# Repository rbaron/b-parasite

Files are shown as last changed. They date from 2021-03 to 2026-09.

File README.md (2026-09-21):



# b-parasite
<p align="center">
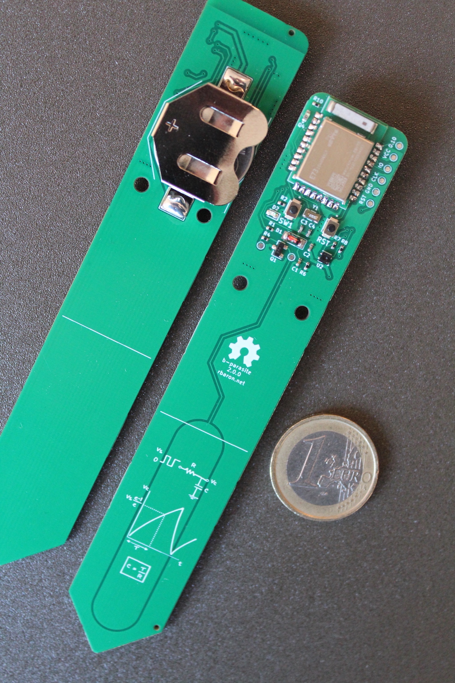
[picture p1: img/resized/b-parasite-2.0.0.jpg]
PCB front and back photo
  
</p>

b-parasite is an open source soil moisture and ambient temperature/humidity/light sensor.

# Features
* Capacitive Soil moisture sensor - see [this blog post](https://rbaron.net/blog/2021/04/05/How-capacitive-soil-moisture-sensors-work.html), [this Twitter thread](https://twitter.com/rbaron_/status/1367182806368071685), and [this post](https://wemakethings.net/2012/09/26/capacitance_measurement/) for nice resources on how they work
* Air temperature and humidity sensor using a [Sensirion's SHTC3](https://sensirion.com/media/documents/643F9C8E/63A5A436/Datasheet_SHTC3.pdf)
* Light sensor using an [ALS-PT19](https://en.everlight.com/wp-content/plugins/ItemRelationship/product_files/pdf/ALS-PT19-315C-L177-TR8_V8.pdf) phototransistor
* Powered by a common CR2032 coin cell, potentially for over two years
* Support for [nRF52840](https://www.nordicsemi.com/products/nrf52840) and [nRF52833](https://www.nordicsemi.com/products/nrf52833) modules
* Open hardware and open source design

# Software
This repository also hosts a few different firmware samples for b-parasite.

|Sample|Description|Extra Documentation|
|---|---|---|
|[samples/ble](./code/samples/ble)|This is the most battle-tested and useful firmware. It periodically reads all sensors and broadcast them via Bluetooth Low Energy (BLE). It works with [Home Assistant](https://www.home-assistant.io/) + [BTHome](https://bthome.io/) out of the box. |[Docs](./code/samples/ble/README.md)|
|[samples/zigbee](./code/samples/zigbee)| An experimental/educational/exploratory basic Zigbee sample built on [nRF Connect + ZBOSS](https://developer.nordicsemi.com/nRF_Connect_SDK/doc/latest/nrf/ug_zigbee.html). It integrates with [Home Assistant](https://www.home-assistant.io/) via [ZHA](https://www.home-assistant.io/integrations/zha) or [Zigbee2MQTT](https://www.zigbee2mqtt.io/). |[Docs](./code/samples/zigbee/README.md)|
|[samples/blinky](./code/samples/blinky)| The classic "Hello, world" |-|
|[samples/soil-read-loop](./code/samples/soil-read-loop)| Reads the soil moisture sensor on a loop. Useful for experimenting and calibrating the sensor. |-|
|[samples/input](./code/samples/input)| Handles button presses. Useful for power profiling GPIO interrupts and testing debouncing for push switches on [boards that have them](https://github.com/rbaron/b-parasite/wiki/Hardware-Versions). |-|

# Documentation
Information about how to order, assemble, build the samples, protect the sensor and flash the firmware is on [the Wiki](https://github.com/rbaron/b-parasite/wiki).

# Repository Organization
* [code/](./code/) - A [`west workspace`](https://docs.zephyrproject.org/latest/develop/west/workspaces.html) containing the common `prstlib` module library and samples, built with Nordic's [nRF Connect SDK](https://www.nordicsemi.com/Products/Development-software/nrf-connect-sdk).
* [kicad/](./kicad/) - KiCad schematic, layout and fabrication files for the printed circuit board (PCB)
* [data/](data/) - data for testing and sensor calibration
* [bridge/](bridge/) - an [ESPHome](https://github.com/esphome/esphome)-based BLE-MQTT bridge
* [case/](case/) - a 3D printable case

<p align="center">
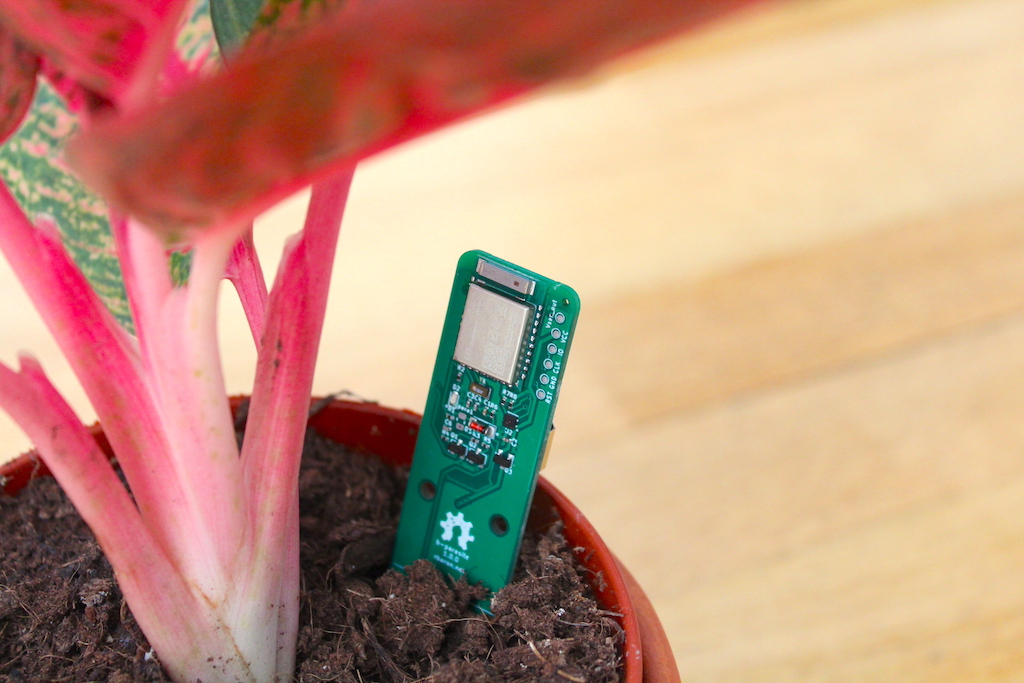
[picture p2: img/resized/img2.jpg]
b-parasite stuck into a small plant vase
  
</p>

# Case
<p align="center">
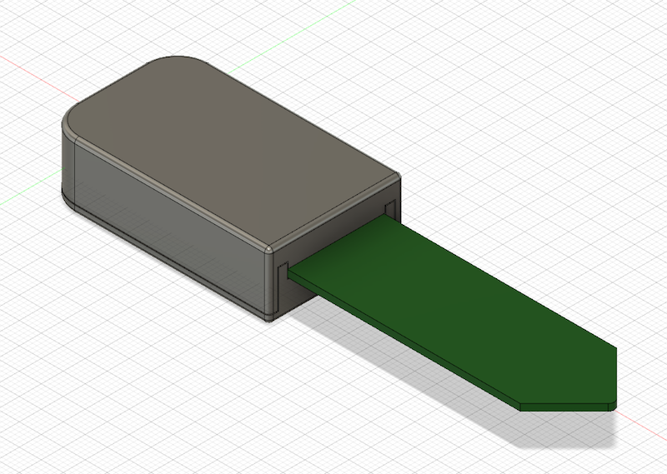
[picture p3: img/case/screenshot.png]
Render of the original 3D printable case
  
</p>

We have three different 3D-printable cases:
1. Original snap-on case - [case/Top.stl](./case/Top.stl), [case/Bottom.stl](./case/Bottom.stl)
2. High airflow - [case/b_parasite_case_high_airflow.stl](./case/b_parasite_case_high_airflow.stl)
3. Mushroom-style - available on [Printables](https://www.printables.com/model/456571-mushroomcap-for-b-parasite-soil-moisture-sensor)
4. b-parasite Hat - available on [Printables](https://www.printables.com/model/901220-waterproof-case-for-b-parasite-soil-moisture-air-s)

# Accessories

Designs and hardware to help you, when building your own:
1. Desk holder for b-parasites [Printables](https://www.printables.com/de/model/566974-b-parasite-holder)

# License
The hardware and associated design files are released under the [Creative Commons CC BY-SA 4.0 license](https://creativecommons.org/licenses/by-sa/4.0/).
The code is released under the [MIT license](https://opensource.org/licenses/MIT).

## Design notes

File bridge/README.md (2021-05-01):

# What's a Bridge (or a Hub)?
b-parasite periodically broadcasts its sensors readings via bluetooth low energy (BLE). Usually, a bridge (a separate device) is used for capturing those broadcasts, decoding them, and forwarding them somewhere else (like MQTT or directly to a database).

# An ESPHome-based Example Bridge
This directory contains a hub implementation based on the [ESPHome project](https://github.com/esphome/esphome/), which runs on the popular [ESP32](https://www.espressif.com/en/products/socs/esp32) microcontrollers.

The `parahub.yaml` file defines an ESPHome project using the `b_parasite` platform. This platform has not yet been merged in the official ESPHome repository, so if you want to use this example bridge, you'll need to use the [rbaron/esphome](https://github.com/rbaron/esphome) fork.

## Secrets
`parahub.yaml` contains some directives such as `!secret mqtt_password`, which instructs it to read secrets from a `secrets.yaml` file.

This file is usually not commited to version control, so you'll need to populate your own. Here's an example:

```yaml
# Example secrets.yaml
wifi_ssid: WIFI_NETWORK_NAME
wifi_password: WIFI_PASSWORD
mqtt_broker: MQTT_BROKER
mqtt_password: MQTT_PASSWORD
ota_password: OTA_PASSWORD
```

# Alternative
[parasite-scanner](https://github.com/rbaron/parasite-scanner) is a purpose-built BLE-MQTT bridge for b-parasites, and runs on Linux and macOS.

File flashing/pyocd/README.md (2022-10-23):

# Flashing with pyocd

This is a different approach to flash the firmware on the b-parasites. It is completely optional.

## Basic instructions

(Based on the discussion in issue #67)

The instructions will probably differ slightly depending on your debugging probe and hardware setup.

The setup is fairly straightforward and documented in the `pyocd` [docs](https://pyocd.io/).

I used an inexpensive debugging probe from Aliexpress called `nanoDAP` from `Muse Labs` which is less than 10 € and readily available. The J-LINKs are hard to get and quite expensive. In my understanding basically all `CMSIS-DAP`-compatible probes which are recognized by `pyocd` should work.

After connecting the debugging probe via usb and connecting the b-parasite as described in the wiki, flashing was easy and fast.

For a complete flashing of softdevice and firmware use the provided python script. Assuming you put the `*.hex` files in default locations it boils down to one simple command:

```
python ./flash_firmware.py
```

For help and documentation of the available command line flags use

```
python ./flash_firmware.py -h
```

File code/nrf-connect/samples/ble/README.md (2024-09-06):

# Bluetooth Low Energy (BLE)
In this sample, b-parasite sensors are periodically read and broadcast using Bluetooth Low Energy (BLE) dvertising packets.

## Configuration
Available configurations and their default values are in [`Kconfig`](./Kconfig). They are set in [`prj.conf`](./prj.conf). Here are some notable examples.

### Sleep Interval
To save energy, the board spends most of the time in a "deep sleep" state, in which most peripherals and radio are completely turned off. The period of sleep is controlled by the `PRST_SLEEP_DURATION_SEC` config.

### Advertising Duration
When it wakes up, the sample reads all sensors and keep broadcasting advertising packets for `PRST_BLE_ADV_DURATION_MSEC` before going back to sleep.

### Advertising Packet Encoding
There are different ways to encode the sensor data in a BLE advertising packet.

#### BTHome Encoding
[BTHome](https://bthome.io) is a new (as of Dec/2022) open standard for encoding sensor data in BLE applications. [Home Assistant](https://www.home-assistant.io/integrations/bthome/) supports it out of the box. This makes the deployment extra convenient, since no additional configuration is needed - Home Assistant will automatically detect b-parasites in range.

What's even more interesting is that by employing [ESPHome](https://esphome.io/) bridges with the [`bluetooth_proxy`](https://esphome.io/components/bluetooth_proxy.html) component, the range of BLE coverage can be transparently increased. Multiple ESPHome bridges will forward received BLE broadcasts to Home Assistant.

This is what a typical deployment with BTHome looks like:
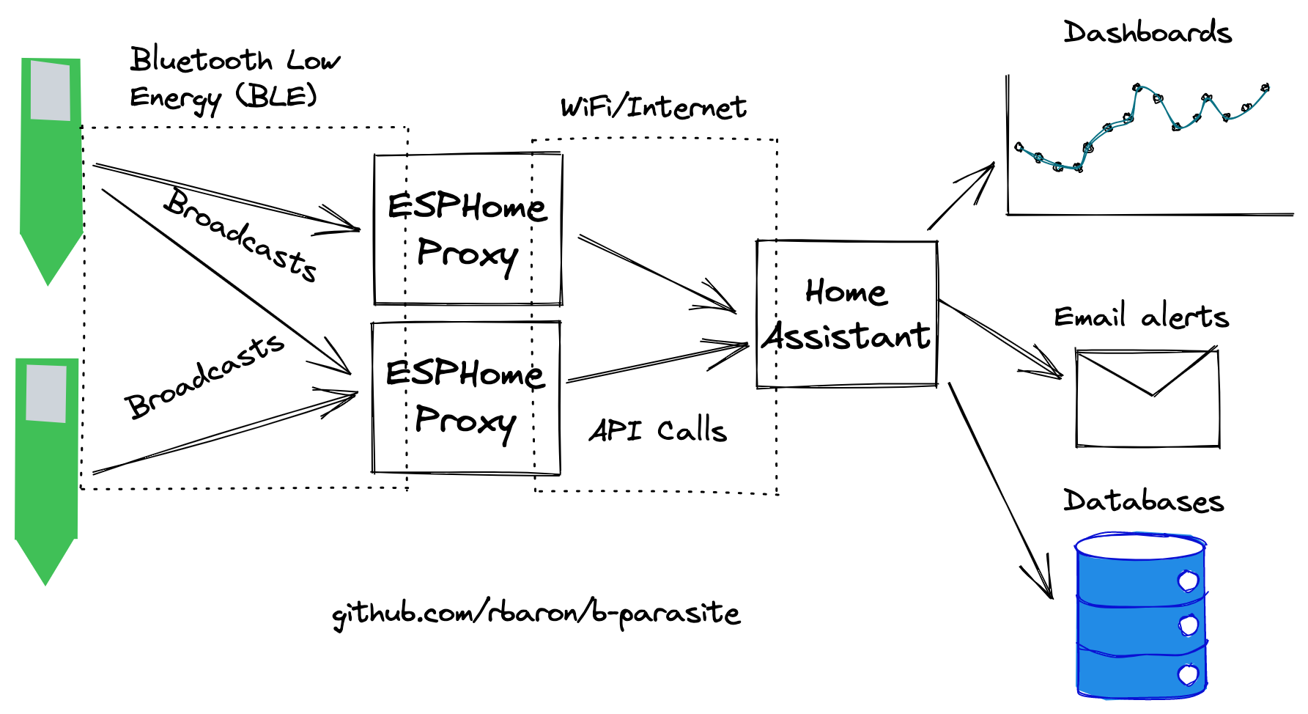
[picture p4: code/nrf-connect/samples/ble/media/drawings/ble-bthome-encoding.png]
Topology with BTHome + Home Assistant


There are two versions of BTHome encodings supported by this sample:
* `PRST_BLE_ENCODING_BTHOME_V2=y` (**default**) uses the [BTHome V2](https://bthome.io/format/), supported by Home Assistant since version `2022.12`
* `PRST_BLE_ENCODING_BTHOME_V1=y` uses the [legacy BTHome V1](https://bthome.io/v1/), which was briefly in use
#### b-parasite Encoding
`PRST_BLE_ENCODING_BPARASITE_V2=y` selects the legacy encoding, used historically in this project. This is the encoding that the [`b_parasite`](https://esphome.io/components/sensor/b_parasite.html) ESPHome component understands.

With this encoding and a ESPHome + `b_parasite` component, this is an usual deployment topology:

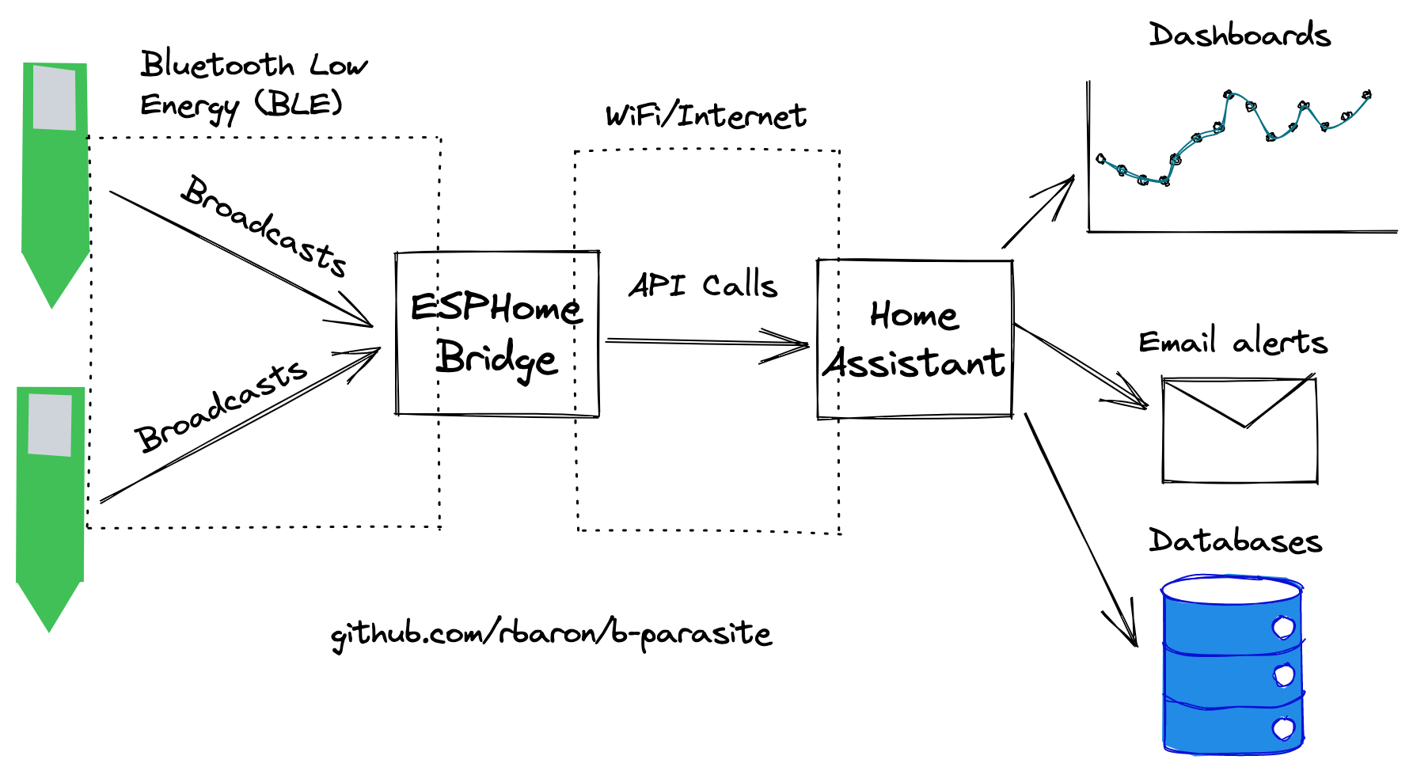
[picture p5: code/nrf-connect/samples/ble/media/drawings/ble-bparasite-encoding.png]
Topology with Legacy encoding + Home Assistant


The disadvantages of this encoding are:
- Each b-parasite has to be configured in the ESPHome component
- Range is limited, unless multiple ESPHome bridges are deployed with the same static configuration

## Battery Life
**tl;dr**: Theoretically well over two years with default settings.

While in deep sleep, the board consumes around `3.0 uA`:

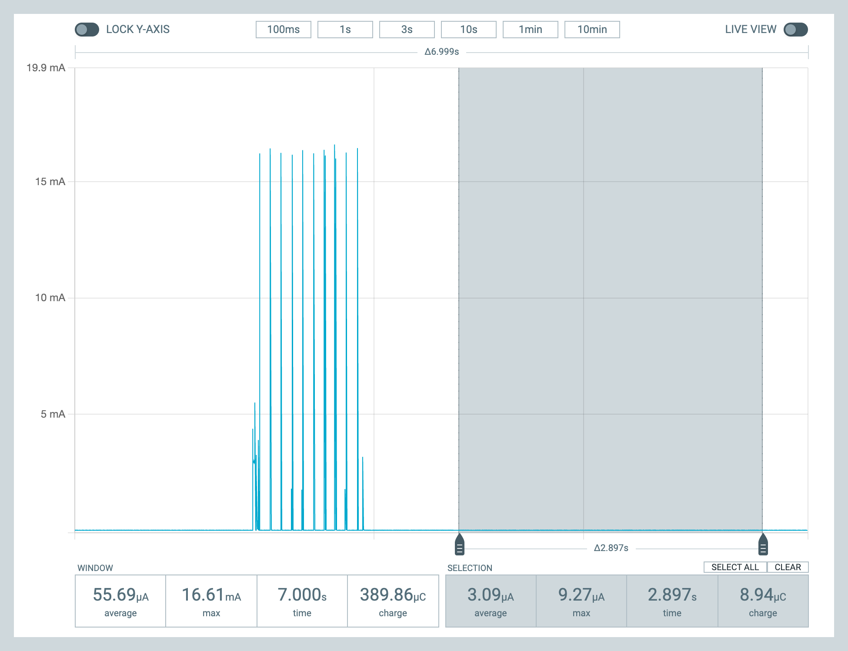
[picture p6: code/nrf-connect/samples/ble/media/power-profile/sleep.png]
Sleep current consumption


In the active broadcasting state, the average power consumption is highly dependant on the advertising interval.

With the default settings (in the `[30, 40] ms` range), we see an average of around `810 uA`:

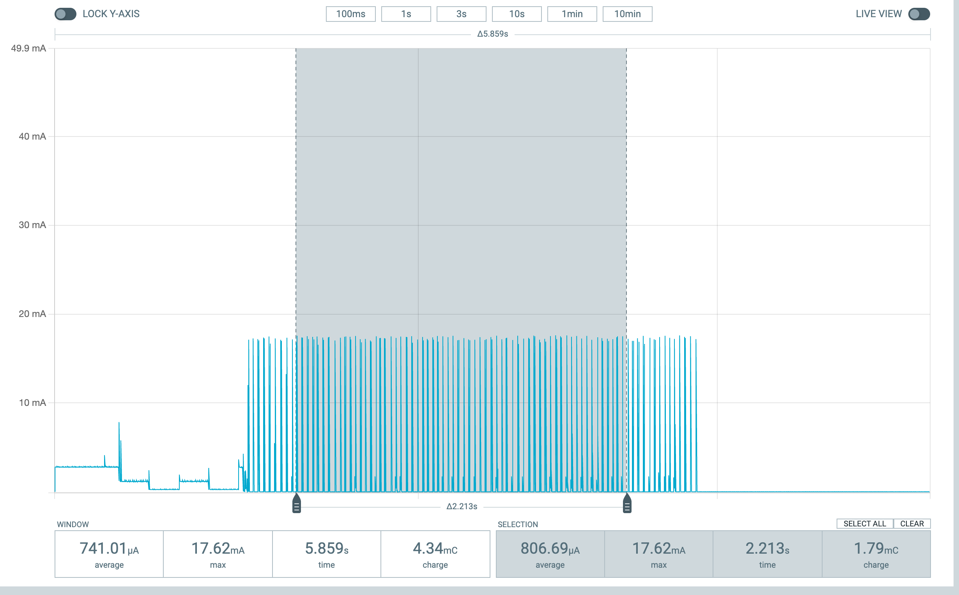
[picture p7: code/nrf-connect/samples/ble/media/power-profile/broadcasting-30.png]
Broadcasting with 30 ms current consumption


If for example we lower the connection interval to the SDK defaults (`[100, 150] ms`, roughly trading off range for power), the average current consumption is around `345 uA`:

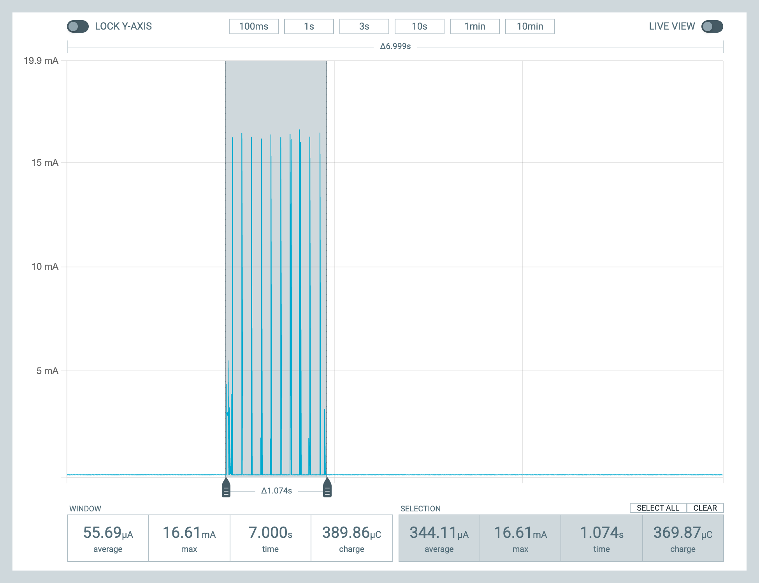
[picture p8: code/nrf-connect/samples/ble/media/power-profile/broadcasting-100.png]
Broadcasting with 100ms current consumption


With a `200 mAh` CR2032 battery, we can use [this spreadsheet](https://docs.google.com/spreadsheets/d/157JQiX20bGkTrlbvWbWRrs_WViL3MgVZffSCWRR7uAI/edit#gid=0) to estimate the battery life to over two years. Note that this is a simplified model and results in practice may vary.

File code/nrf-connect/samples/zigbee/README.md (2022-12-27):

# Zigbee firmware sample
This sample is adapted from the [zigbee_template](https://developer.nordicsemi.com/nRF_Connect_SDK/doc/latest/nrf/samples/zigbee/template/README.html) from the nRF Connect SDK. It's a basic experimental/educational/exploratory firmware sample for b-parasite.

## Clusters
These [clusters](https://en.wikipedia.org/wiki/Zigbee#Cluster_library) are defined in the sample:

|Cluster ID|Name|
|---|---|
|0x0001|Power Configuration|
|0x0400|Illuminance Measurement|
|0x0402|Temperature Measurement|
|0x0405|Relative Humidity Measurement|
|0x0408|Soil Moisture Measurement|

## Pairing Mode
The sample will first boot and start looking for a Zigbee coordinator - in pairing mode. The onboard LED will be flashing once a second while in this mode. Once a suitable network is found, the LED will briefly flash 3 times and remain off.

### Factory Reset
A factory reset will make b-parasite forget its network pairing information and switch to pairing mode. There are two (mutually exclusive) methods to perform a factory reset, controlled by the `CONFIG_PRST_ZB_FACTORY_RESET_METHOD` config flag.

#### Factory Reset Method 1 (default) - Double reset
Resetting b-parasite twice in the timestamp of 5 seconds will perform a factory reset. With this method, both shorting the `RST` pin to ground and removing-inserting the battery counts as a reset.

For better results, wait > 1 and < 5 seconds second between the resets. The LED will flash a total of 8 times to indicate it worked.

#### Factory Reset Method 2 - Reset Pin
In this method, there's a distinction between two reset modes.

#### Power up mode
The device enters this mode when it is powered. For example, swapping an old battery or connecting to eternal power. This is the "usual" reset mode, and joined networks will be remembered.

#### Reset pin mode
If the device's RESET pin is briefly grounded, the device will effectively be **factory reset**. The device will leave its previous network and start looking for a new one.

While it works, this method can be finicky - an accidental pin reset will perform an unwanted factory reset.

## Configs
Available options in `Kconfig`. Notable options:
* `CONFIG_PRST_ZB_SLEEP_DURATION_SEC`: amount of time (in seconds) the device sleeps between reading all sensors and updating its clusters
* `CONFIG_PRST_ZB_PARENT_POLL_INTERVAL_SEC`: amount of time (in seconds) the device waits between polling its parent for data

## Home Assistant Integration
This firmware sample has only been tested with Home Assistant, using one of the following integrations.

### Zigbee Home Automation (ZHA)
With the [ZHA](https://www.home-assistant.io/integrations/zha) Home Assistant integration, b-parasite should work out of the box.

### Zigbee2MQTT & Home Assistant
With [Zigbee2MQTT](https://zigbee2mqtt.io/), a custom converter is required. The [b-parasite.js](b-parasite.js) file contains such a converter. See [Support new devices](https://www.zigbee2mqtt.io/advanced/support-new-devices/01_support_new_devices.html) for instructions.

## Battery Life
While sleeping, the device consumes around 2 uA:
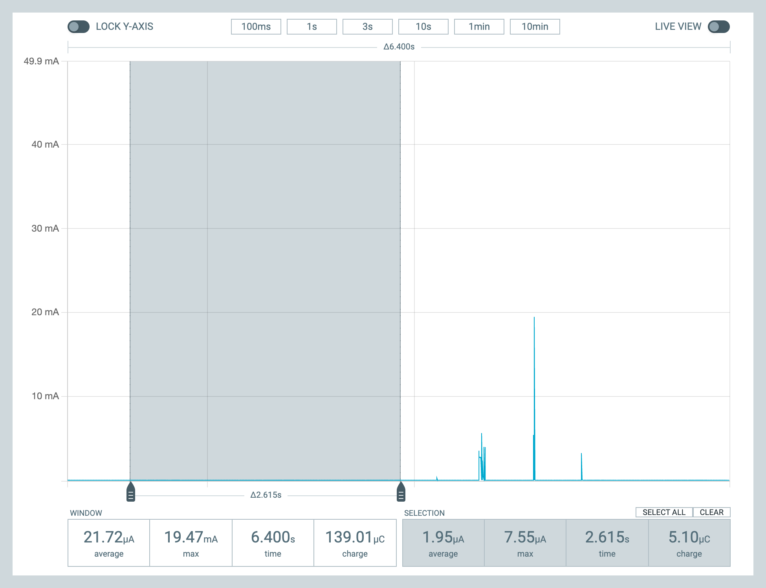
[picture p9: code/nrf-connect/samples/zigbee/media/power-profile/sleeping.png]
sleeping current

In the active cycle, it averages around 125 uA for 1 second:
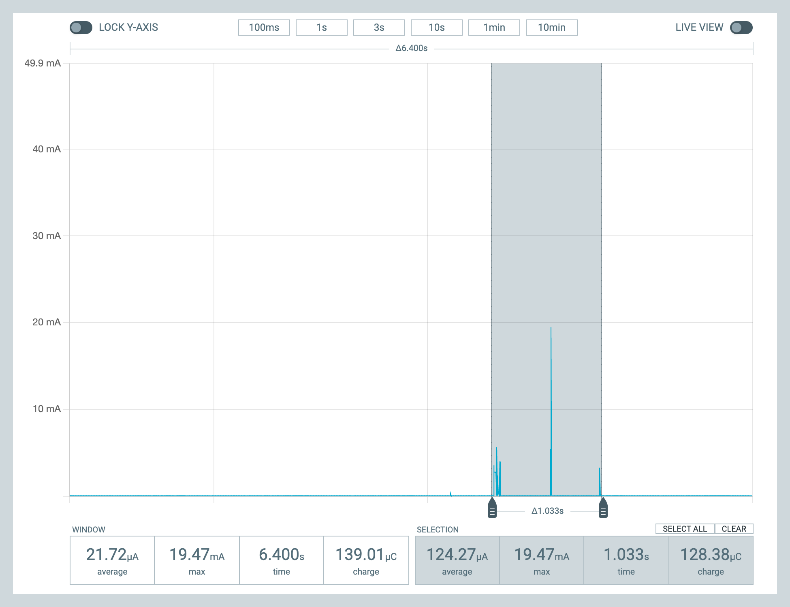
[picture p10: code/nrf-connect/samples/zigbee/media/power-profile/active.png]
active current


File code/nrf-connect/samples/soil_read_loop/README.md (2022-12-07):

# Calibration
A sample for calibrating b-parasites soil moisture analog-to-digital conversion.

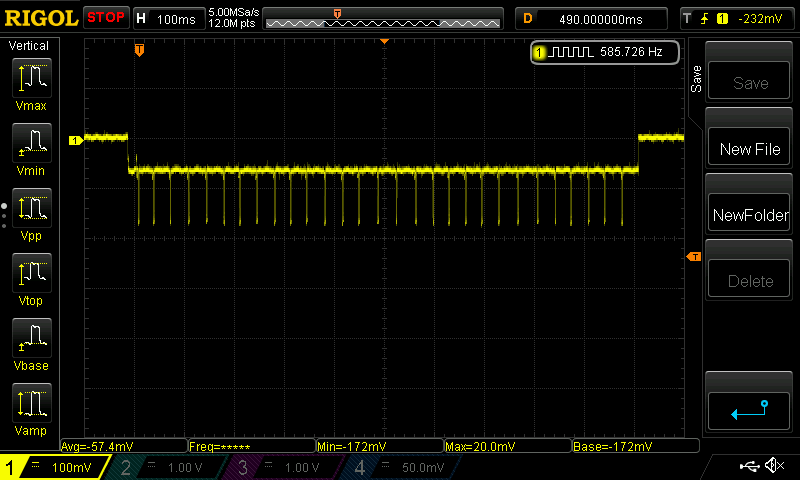
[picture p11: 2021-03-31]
img/scope/0dbm-no-led-across-10ohm.png

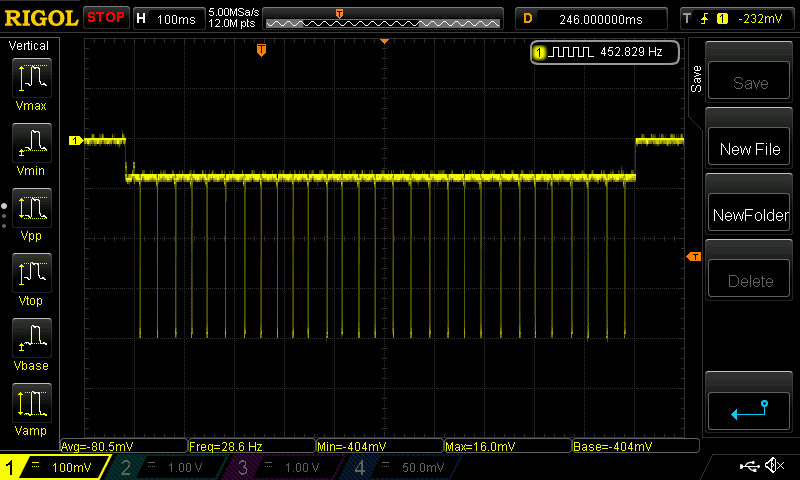
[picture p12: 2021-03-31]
img/scope/8dbm-across-10ohm.png

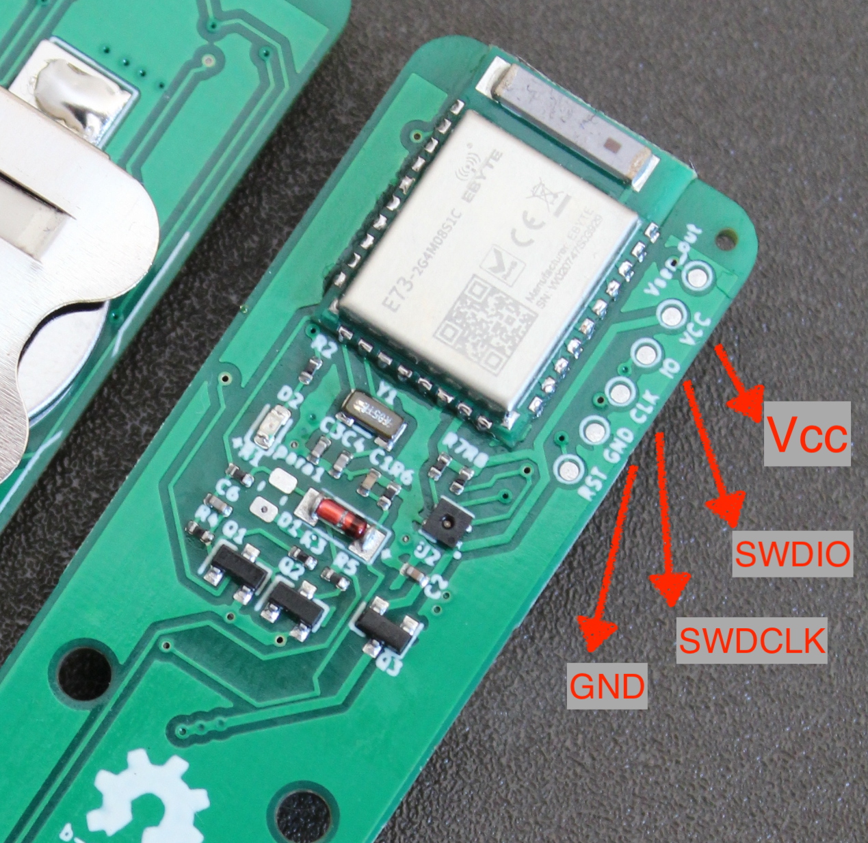
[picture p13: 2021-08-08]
img/wiki/swdpins.jpg

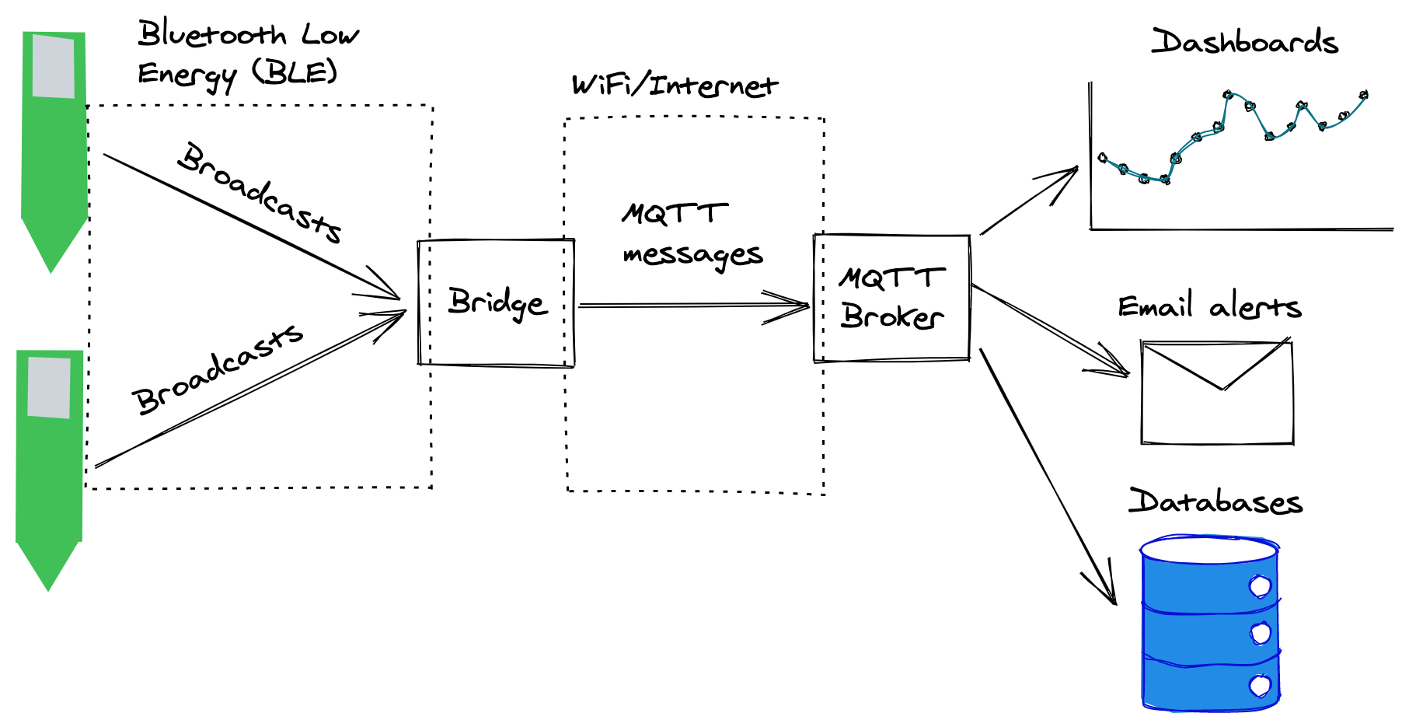
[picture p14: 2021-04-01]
img/excalidraw/diagram.png

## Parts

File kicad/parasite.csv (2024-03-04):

Comment | Designator | Footprint | LCSC
Battery_Cell | BT1 | kicad:BatteryHolder_Keystone_3002_1x2032
1n | C1 | Capacitor_SMD:C_0402_1005Metric | C1523
100n | C2 | Capacitor_SMD:C_0402_1005Metric | C1525
12p | C3,C4 | Capacitor_SMD:C_0402_1005Metric | C1547
LL4148 | D1 | Diode_SMD:D_MiniMELF | C3011166
LED | D2 | LED_SMD:LED_0603_1608Metric | C2286
MMBT3906 | Q1 | Package_TO_SOT_SMD:SOT-23 | C2910191
Q_Photo_NPN | Q4 | snapeda:TR8 | C146233
10k | R1,R4,R7,R8 | Resistor_SMD:R_0402_1005Metric | C25744
470 | R10 | Resistor_SMD:R_0402_1005Metric | C25117
1k | R2 | Resistor_SMD:R_0402_1005Metric | C11702
1M | R6 | Resistor_SMD:R_0402_1005Metric | C26083
B3U-1000P | RST1,SW1 | SW_B3U-1000P | C231329
E73-2G4M08S1C | U1 | snapeda:E73-2G4M08S1C | C356849
SHTC3 | U2 | kicad:Sensirion_DFN-4-1EP_2x2mm_P1mm_EP0.7x1.6mm | C194656
32.768kHz | Y1 | Crystal:Crystal_SMD_3215-2Pin_3.2x1.5mm | C32346

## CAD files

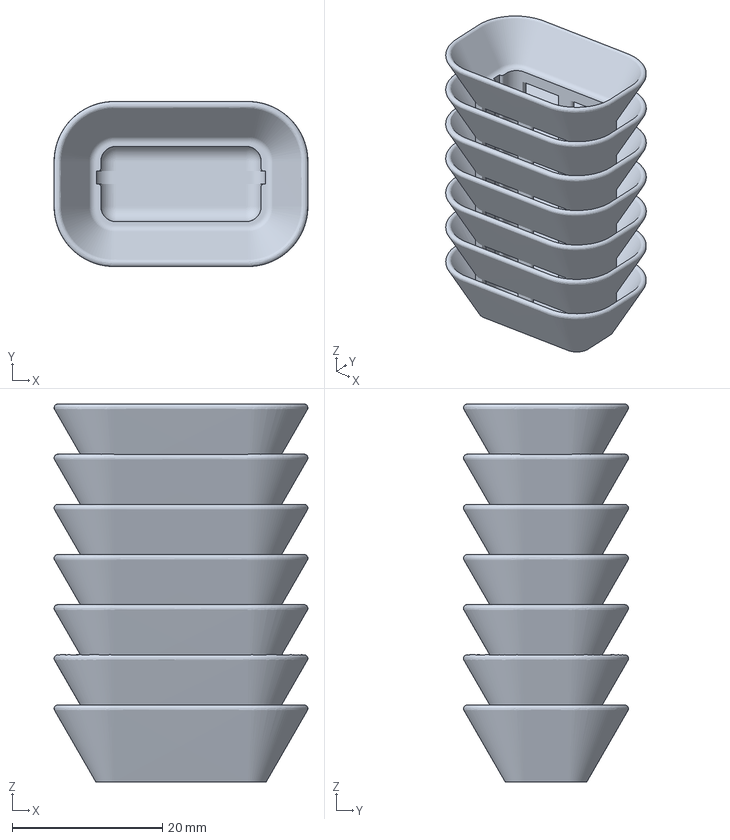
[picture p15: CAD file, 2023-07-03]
case/b_parasite_case_high_airflow.3mf
33.7 x 21.9 x 50.3 mm

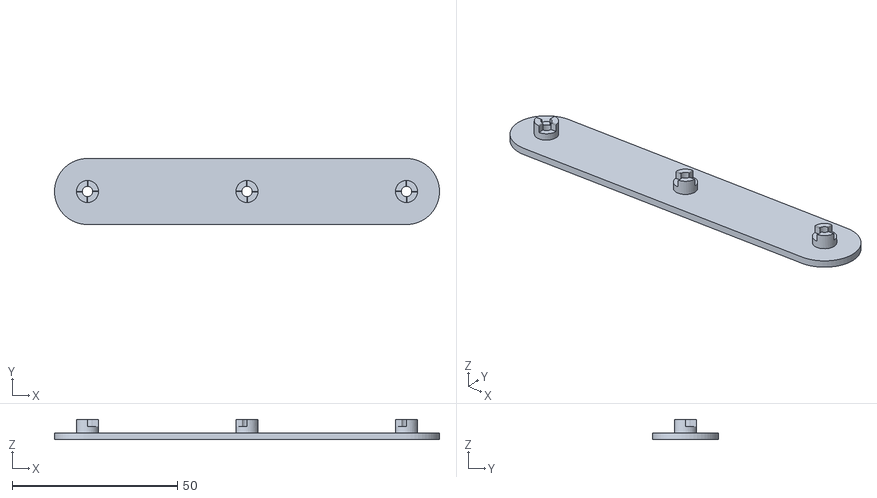
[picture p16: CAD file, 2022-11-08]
experimental/rotisserie/base.stl
116.6 x 20.0 x 6.15

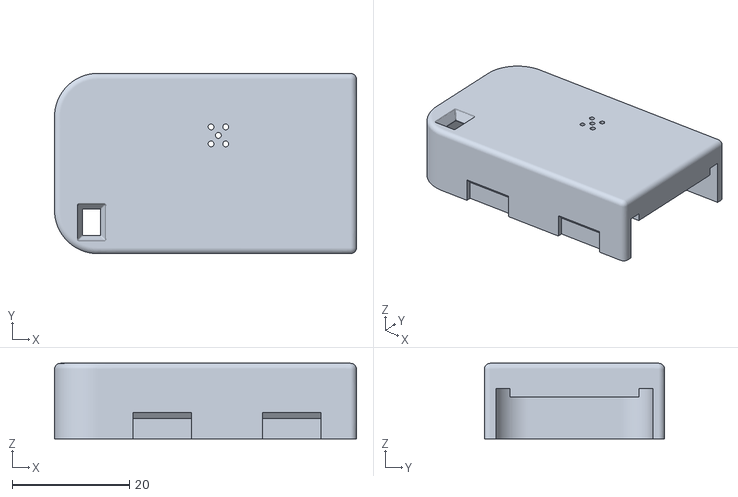
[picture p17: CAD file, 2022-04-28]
case/Top-holes.stl
51.6 x 30.8 x 12.9

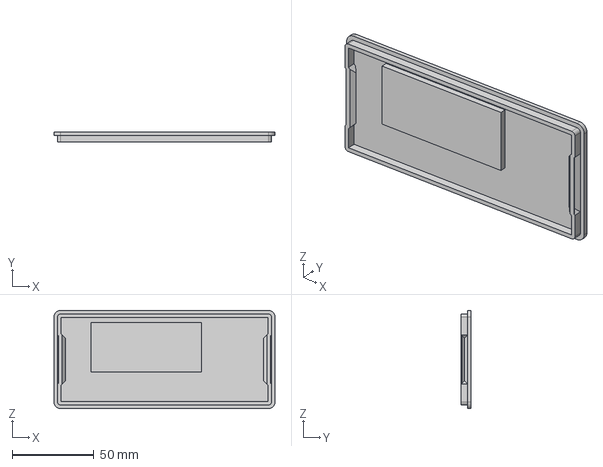
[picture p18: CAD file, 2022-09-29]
experimental/rotisserie/rotisserie.step
135.0 x 6.00 x 60.0 mm

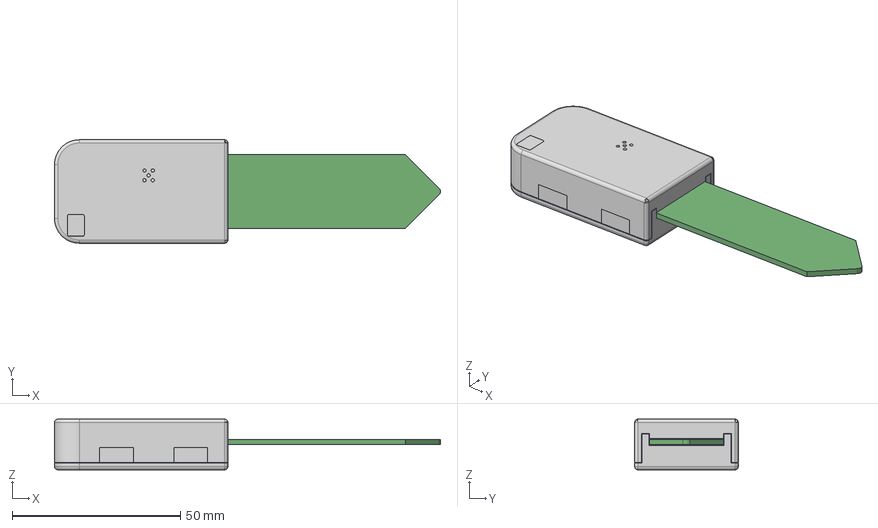
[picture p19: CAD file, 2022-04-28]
case/Case.step
114.8 x 30.8 x 15.1 mm
Case_1

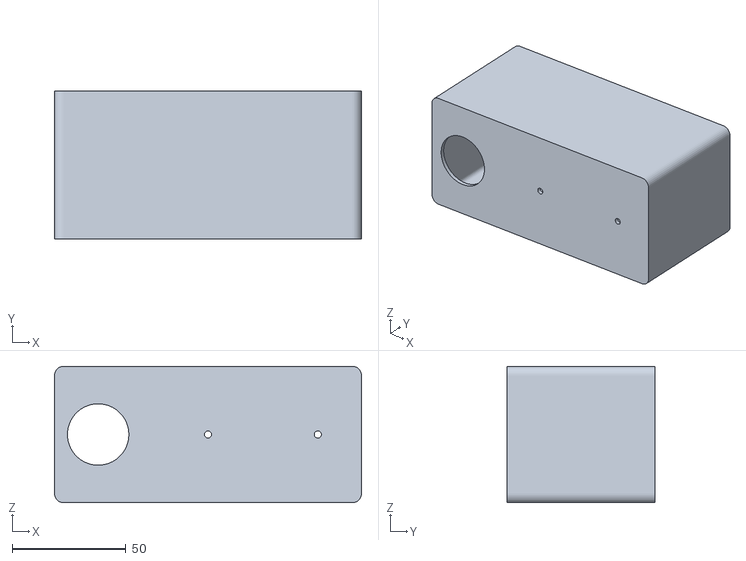
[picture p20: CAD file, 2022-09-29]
experimental/rotisserie/case.stl
135.0 x 65.0 x 60.0

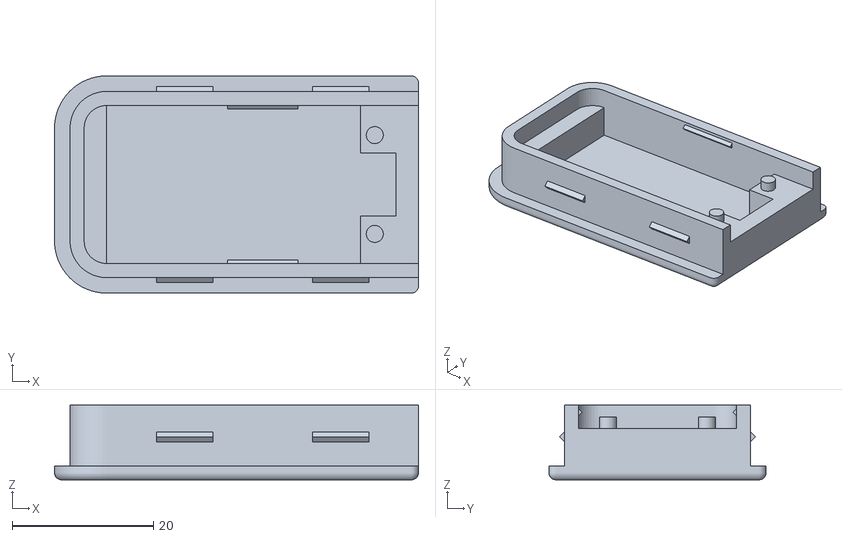
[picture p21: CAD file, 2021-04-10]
case/Bottom.stl
51.6 x 30.8 x 10.6

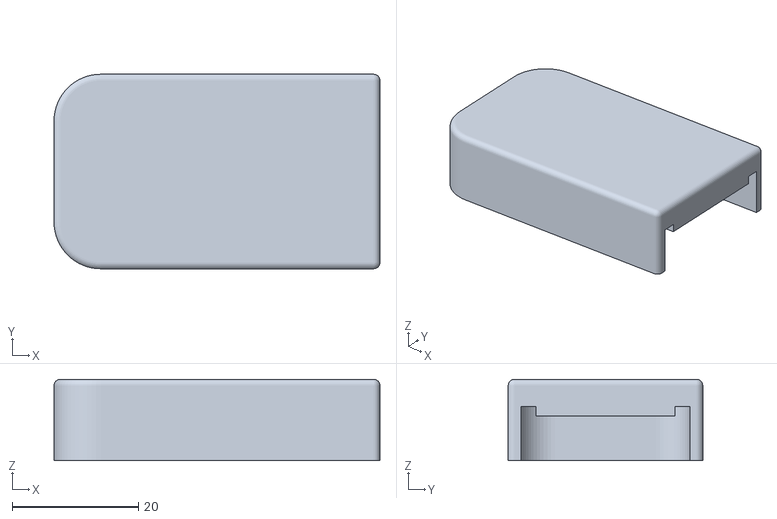
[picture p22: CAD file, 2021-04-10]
case/Top.stl
51.6 x 30.8 x 12.9

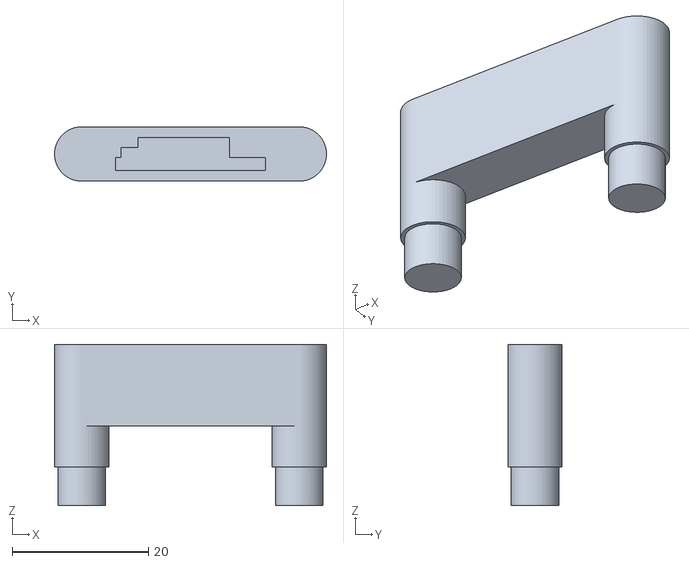
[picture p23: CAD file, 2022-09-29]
experimental/rotisserie/holder.stl
40.0 x 8.00 x 23.7

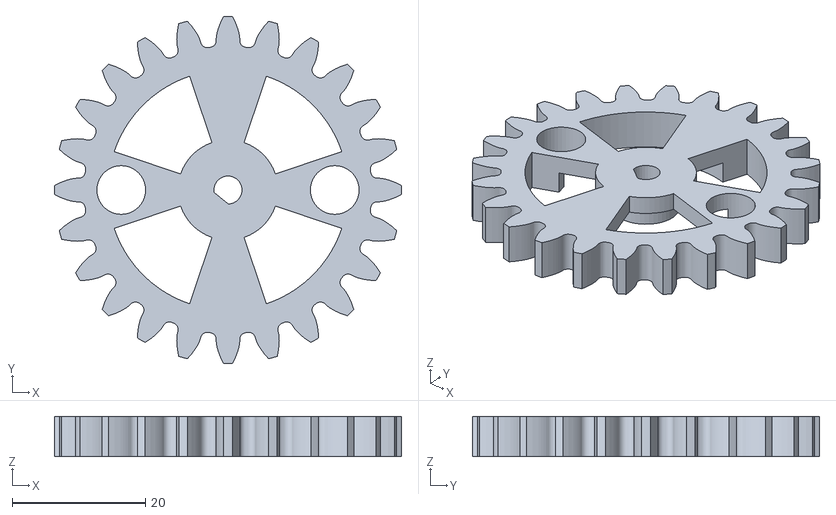
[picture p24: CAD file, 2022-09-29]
experimental/rotisserie/gear_motor.stl
52.0 x 52.0 x 6.00

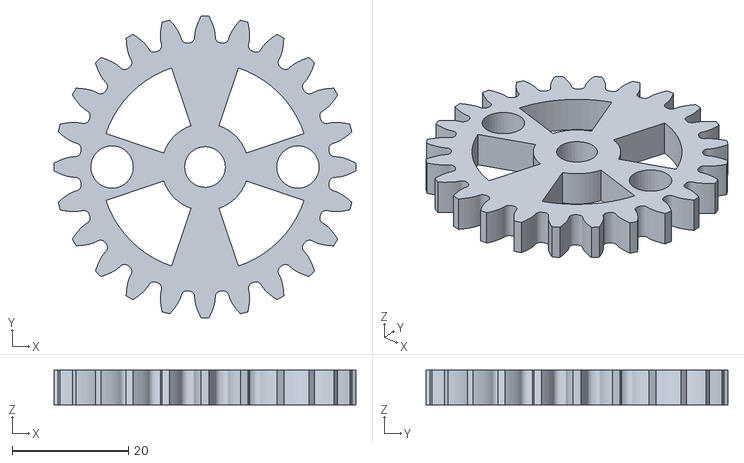
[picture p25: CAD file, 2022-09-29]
experimental/rotisserie/gear.stl
52.0 x 52.0 x 6.00

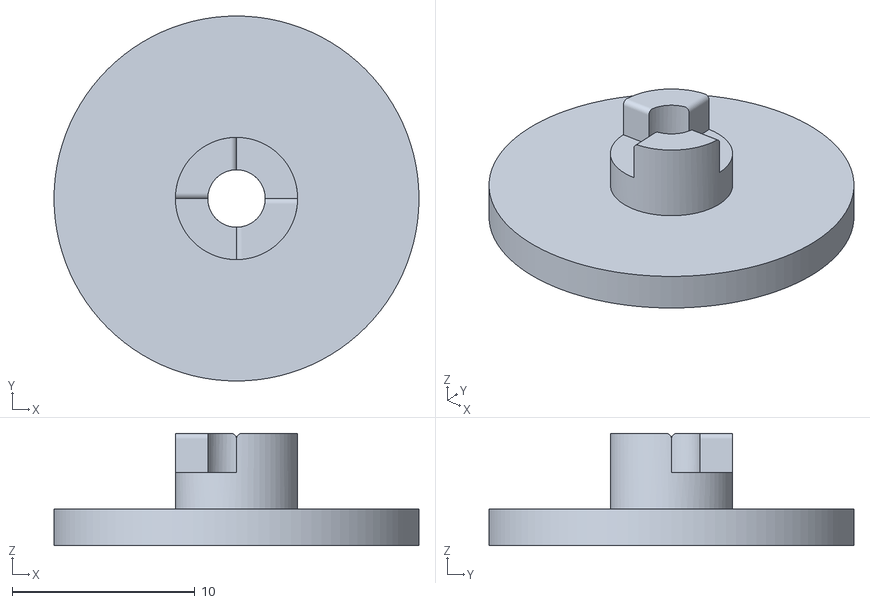
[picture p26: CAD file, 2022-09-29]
experimental/rotisserie/gear_cap.stl
20.0 x 20.0 x 6.15

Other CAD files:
experimental/rotisserie/lid.stl
case/b_parasite_case_high_airflow.stl

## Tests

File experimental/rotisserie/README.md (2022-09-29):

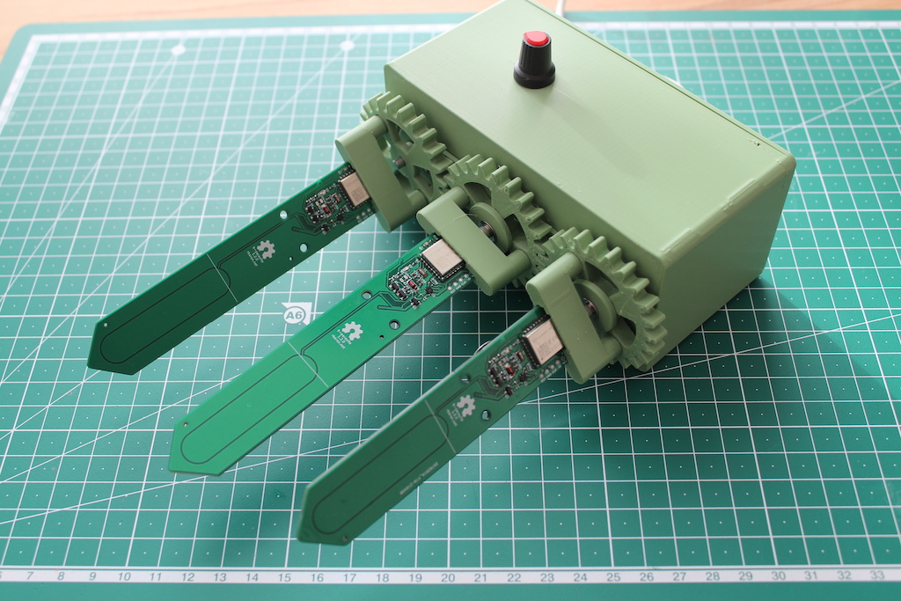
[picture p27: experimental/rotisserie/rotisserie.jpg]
Photo of the rotisserie with three b-parasites attached


This is a silly attempt of making an automatic spinning jig. Don't take it too seriously - there are probably many easier, less dramatic ways to achieve the same results.

## Parts
| Part | Example |
|---|---|
| DC motor - 12V, 60 rpm | [Aliexpress](https://www.aliexpress.com/item/32987942205.html) |
| PWM speed controller | [Aliexpress](https://www.aliexpress.com/item/33005893596.html) |
| 12V power supply | [Aliexpress](https://www.aliexpress.com/item/32798499158.html) |
| Power supply female jack  | [Aliexpress](https://www.aliexpress.com/item/1005004763316462.html) |
| M3 screws, washers & nuts | [Aliexpress](https://www.aliexpress.com/item/1005001975621423.html) |

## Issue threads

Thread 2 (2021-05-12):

Moisture readings overflow

AlexSzlavik, 2021-05-12:
I haven't dug into this myself yet, but noticed this morning that one of my plants moisture reading "overflowed". When looking at the code, I saw that moisture readings are actually fit to a polynomial and the final values from the equation. Haven't done any debugging yet, so probably not much to go on, but opening the issue as something is clearly miss-behaving. Will follow up as I get time.
I'm also not convinced that the moisture reading is right in the first place. It's continuously trending up, yet I haven't added water to the soil since adding the sensor.

Love this project, thanks a bajillion for open sourcing.

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

rbaron, 2021-05-12:
Hi @AlexSzlavik,

It's super cool that you made some boards yourself!

The overflow issue should have been fixed in [this commit](https://github.com/rbaron/b-parasite/commit/f0b3294f0f77db032b2625e03c2066ef8001ea5c). The bug was multiplying the percentage by 2 << 16 instead of (2 << 16) - 1, so it could overflow an `uint16_t`. Do you know if you're running a version that has that commit?

About the "initial upwards trend", this is a phenomenon I also experienced with a couple of boards (and so did a colleague to whom I gifted one). For example, check out the first data I have from when I initially put a few sensors in the ground:

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

(The orange curve is even sensitive to the air humidity through the day!)

This is a little noisy, but there's definitely some initial upwards trend there. I don't know for sure why, but some hypotheses are:
* Moisture penetrating in the solder mask layer tiny pores
* Some water capillarity/surface tension that causes water droplets to start accumulating on the sensor surface
* Simply the soil accommodating itself around the sensor after being compressed by inserting the board, increasing the "contact" it makes with the board

Another interesting data point is that I recently deployed two new sensors, but I coated them completely (even over the components, except the temperature sensor) with [this protective spray (PLASTIK 70)](http://www.kontaktchemie.com/koc/KOCproductdetail.csp?division=&product=PLASTIK%2070&ilang=en&plang=en). There I haven't observed this initial upwards trend (the yellow bump is when I watered it a little bit):

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

I'll try and replicate this again with new coated boards with different types of soil. I'd also love to see how your sensor behaves in the next days/weeks.

Thanks!

AlexSzlavik, 2021-05-13:
Fantastic response, thank you!
Sorry about posting without the patch, I was too excited when I finally put it together that I forgot to pull the latest 🤦 . Will run latest and check again.

As for the upward trend, I suspect you are onto something with capillarity effect. When I pulled the sensor out it was noticeably "wet". That is, far more wet than I'd have expected on this particular plant. I've attached a couple images to show the level of "wet" dirt stuck to the capacitance section. I also think that there may be some issues with my soldermask. The second image clearly shows "bubbles" forming under the soldermask, likely moisture build up. I have some conformal coating I could apply around the base to waterproof it, but I'm worried what the impact on the capacitance reading will be.
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

rbaron, 2021-05-13:
The board looks super cool in black! Thanks for the photos.

I've also seen this surprising moisture accumulation around the sensor and that got me thinking about this effect.

Those bubbles I haven't seen, but I think it's one more reason for us to use a layer of conformal coating. I've tried to recalibrate the sensor after applying the spray and I found the difference to be negligible. I'm still using the same values for both coated and uncoated boards. I imagine the added layer is so thin that the variation in the dielectric is super tiny.

It seems the location of the sensor (closer/further from the root) and specially how much contact it makes with the soil have greater effect on the read values than the protective coating.  Still, I think even those greater effects are okay for the level of precision we are aiming for here.

Let me know if you end up coating the boards - curious to learn about your findings!

hubikj, 2021-05-13:
I read an interesting article about capacitive soil moisture sensors and the author recommends sealing the PCB edges with epoxy:
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
Source: https://thecavepearlproject.org/2020/10/27/hacking-a-capacitive-soil-moisture-sensor-for-frequency-output/

rbaron, 2021-05-13:
Thanks for sharing @hubikj. That's a good reference.

Before using the conformal coating spray, I was applying a layer of transparent nail polish to the sides of the PCB. That seemed to do the trick, but epoxy/conformal coating seems to be the best solution.

AlexSzlavik, 2021-05-13:
Thanks for the discussion and the resources. I've applied a thing film of silicon based conformal coating to the edges and the flat surface. There was no noticeable change in sensitivity (as you said, on the scale we care about). I've replaced the sensor and ran it overnight. I still see some initial creep, but the rate is definitely lower. I'll leave it for a day or two and come back with the results.

MrEinstin, 2021-05-25:
I have been wondering about the effect of conformal coatings on at least the lower sensor part of the pcb as far as any negative effects in it's measurements. Also, some coatings are more prone to moisture ingress than others. There are also other factors to consider if you were to coat the board entirely as far as reparability. Obviously some areas need to be masked so that they aren't coated (humidity sensor, battery holder, programming pads). I happened to run into this comparison from VSI. https://vsiparylene.com/2020/09/10/the-essential-conformal-coating-comparison-guide/

AlexSzlavik, 2021-07-02:
So I changed the coating to a Polyurethane based coat. This has been working really well! I haven't tried the silicon based one again since, but I think I may have also messed up the initial curing process on that coating. Eitherway, as was pointed out in this thread, coating the edges is absolutely key.

rbaron, 2021-07-03:
I'm really glad to hear that @AlexSzlavik. Thanks for coming back and updating the thread!

chucknorris101, 2022-08-14:
Thanks for pointing me this way @rbaron!
@AlexSzlavik For the poly coating, is it just the edges or giving it a nice full dip coat?

AlexSzlavik, 2022-08-15:
I coated the entire device which worked alright. @rbaron also wrote a blog post about how he did his coating which was great!

Closed 2021-07-02.

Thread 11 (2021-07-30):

splitting sensor and RF-part

SchmidL, 2021-07-30:
hi,

I still follow you project very tightly and will soon order my first batch! Unfortunately, I should have order the nRF when there where still more widely available, but at that time the temp sensor was on short. Anyway...
Will waiting I was thinking if it would be possible to split the sensor (parasitic cap) from the rest of the electronics.
1. Would make the waterproofing of the electronics much easier, as I can have the nRF outside of my pots, and just the pcb for sensing in the pot.
2. I have some metal pots, which work kind of as a faraday cage, very bad for the bt-signal.

When checking out the schematics, I see just one connection path (SENS_OUT) to the nRF. So i was thinking just to elongate this path via a cable. Now I'm a bit wondering if it is really that easy, or do I miss something? Thank you anyway for your amazing project!

rbaron, 2021-08-01:
Hi @SchmidL,

That's an interesting idea. I think there are a few ways to split the sensor and RF part, depending on where you cut the design. For example, if you want to remove just the nRF module:

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

1. The `SENS_OUT` is the output, which is sampled by the nRF, like you described;
2. The `PWM` is the input to the sensor, a square wave;
3. There is a "fast discharge" circuit that sort of shorts the `C_sen+` to ground in the PWM low signal. This is done to ensure the `C_sen+` starts at 0 V in the next PWM high phase;

With the current design, I believe you would have to route these 3 signals (plus GND).

Another idea is to remove just the actual parasitic sensor traces (`C_sen+` and `GND` signals), and keep all the input/output & fast discharge circuitry on the outside, together with the nRF:

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

For this, you could even literally cut the current PCB design to try it out:

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

As a last note, if you're willing to route some wires from the pot to outside, one idea is to go one step further and use the same nRF to reading multiple sensors.

I hope this helps!

SchmidL, 2021-08-02:
Hi rbaron,

Thank you very much for your extensive reply and suggestions! Also a very nice idea is to use multiple sensors on one nRF.
I also really like your suggestions for different separation ideas. In my decision phase i don’t really care to have 3 or less wire, although just cutting off the parasitic capacitor was the one I like the most. I will come back when I have implement the different pcb designs.

Your immediate help is really appreciated!!

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

rbaron, 2021-09-30:
Hey @SchmidL, I'll close this issue since there's no activity. Feel free to reopen it!

Closed 2021-09-30.

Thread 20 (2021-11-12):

programming - low voltage detected at the target

SchmidL, 2021-11-12:
hi,

I try to flash the firmware with my J-Link Edu. but unfortunately I get following error? As it's the first time flashing with swd, I cannot figure out what the issue is. After a successful compile, it would like to flash the softdevice part and encounter the following error:
```
% SDK_ROOT=~/Documents/b-parasite-main/code/nRF5_SDK_17.1.0_ddde560 PLATFORM=E73_2G4M08S1E make flash_softdevice
Flashing: s140_nrf52_7.2.0_softdevice.hex
nrfjprog -f nrf52 --program /Users/lorenz/Documents/b-parasite-main/code/nRF5_SDK_17.1.0_ddde560/components/softdevice/s140/hex/s140_nrf52_7.2.0_softdevice.hex --sectorerase
ERROR: Unable to connect to a debugger.
ERROR: Low voltage detected at the target. Please make sure the device is
ERROR: properly supplied.
NOTE: For additional output, try running again with logging enabled (--log).
NOTE: Any generated log error messages will be displayed.
make: *** [flash_softdevice] Error 43
```

same for just make flash, the Vcc is directly connected to the jlink. no coincell involved.
Any ideas? Thx

rbaron, 2021-11-13:
Hi @SchmidL,

Have you taken a look at the [How to Program on the Wiki](https://github.com/rbaron/b-parasite/wiki/How-to-Program)?

Can you show us how you're connecting your J-Link Edu to the target? Think to check:
1. You need to connect 4 wires from the J-Link to the b-parasite. Make sure you're also connecting the GND and Vcc
2. **Take off the battery** if you're connecting the Vcc from the J-Link to the b-parasite.

Please let me know if that helps.

SchmidL, 2021-11-14:
Hi @rbaron,

yes I looked at it but in the end i followed the REAMDE from the /code https://github.com/rbaron/b-parasite/tree/main/code/b-parasite, as there where several issues/errors for me (`make flash-softdevice` is wrong, -> `make flash_softdevice`, `make flash-device` does not exist), but no problem.

Then I connected my J-Link Edu via USB to a USB-C hub to my Mac.
The sensor i connected like that:
- Pin 1 (VTref) to VCC
- Pin 4 (GND) to GND
- Pin 7 (SWDIO) to CLK
- Pin 9 (SWDCLK) to IO

I do not use any coin cell at this stage (to avoid any voltage uncertainty)

Any idea where I can start checking?

rbaron, 2021-11-16:
I just corrected the typos in the Wiki page.

I believe the J-Link EDU cannot power target boards. It means that you need to provide external power to the b-parasite, and also connect VTref to it. One idea is to then leave the battery in or supply 3.3V to it with an external power supply while flashing.

Meroje, 2022-01-14:
I'm using an EDU mini too, it had to have the reset line connected to move past this.

Unfortunately, in my case (with E73_2G4M08S1E modules) it's then looping on `ERROR: [SeggerBackend] - JLinkARM.dll reported "-1", "An unknown error.".` for nrfjprog, or a combination of `ConfigTargetSettings() / InitTarget()` loops with JLinkExe

rbaron, 2022-01-16:
Hi @Meroje. Did you manage to fix it?

I've had my fair share of these frustrating errors. It's hard to pinpoint the root cause from a distance, but from experience it's usually the following, in order of likelihood:

* Double check the GND, SWCLK, SWIO, 3V (provided from an external source if using the J-Link EDU);
* Faulty USB cable. This used to be the last thing I suspect and now it's the first. Consider trying different cables;
* Faulty solder joints/bridging/excess of solder paste. For manually soldered E73 modules, it's a real possibility. Consider ruling this out by trying to program a second b-parasite if you have access to one;
* Faulty programmers - unlikely the case if you're using an original J-Link EDU, but possible for those cheap clones;
* Driver issues. Make sure you have the most up-to-date J-Link drivers installed;

Please let me know if you manage to find the root cause.

Meroje, 2022-01-16:
> * Double check the GND, SWCLK, SWIO, 3V (provided from an external source if using the J-Link EDU);

Probe reports `VTarget = 3.223V`, using an external source (not battery), reseated cables multiple times and checked swio/clk
> * Faulty USB cable. This used to be the last thing I suspect and now it's the first. Consider trying different cables;

tried a few, seems unlikely
> * Faulty solder joints/bridging/excess of solder paste. For manually soldered E73 modules, it's a real possibility. Consider ruling this out by trying to program a second b-parasite if you have access to one;

I hand soldered 2 parasites so far, using rossman levels of flux. I have good confidence joints are ok on both but no way to be sure 100%
> * Faulty programmers - unlikely the case if you're using an original J-Link EDU, but possible for those cheap clones;

bought from adafruit. not sure what other chips I have to check on
> * Driver issues. Make sure you have the most up-to-date J-Link drivers installed;

Tried linux and windows so far
> Please let me know if you manage to find the root cause.

still no luck :/

rbaron, 2022-01-16:
@Meroje can you confirm you get a different error if you don't power the b-parasite?

You can also try issuing the `nrfjprog --reset --log` command. Maybe it will give you a hint of what's happening.

If you want to share a picture of your setup, I can take a look and see if there's anything visibly wrong.

Meroje, 2022-01-16:
removing external power gives the expected "low voltage" error

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
[jlink.log](https://github.com/rbaron/b-parasite/files/7877289/jlink.log)
[nrfjprog.log](https://github.com/rbaron/b-parasite/files/7877290/nrfjprog.log)
```
Connecting ...
 - Connecting via USB to probe/ programmer device 0
 - Probe/ Programmer firmware: J-Link EDU Mini V1 compiled Dec  7 2021 08:38:51
 - Device "NRF52833_XXAA" selected.
 - Target interface speed: 4000 kHz (Fixed)
 - VTarget = 3.167V
 - InitTarget() start
 - InitTarget() end
 - InitTarget() start
 - InitTarget() end
 - ERROR: Failed to connect.
Could not establish a connection to target.
Connecting ...
 - Connecting via USB to probe/ programmer device 0
 - Probe/ Programmer firmware: J-Link EDU Mini V1 compiled Dec  7 2021 08:38:51
 - Device "NRF52833_XXAA" selected.
 - InitTarget() start
 - InitTarget() end
 - InitTarget() start
 - InitTarget() end
 - Target interface speed: 200 kHz (Auto)
 - VTarget = 3.169V
 - InitTarget() start
 - InitTarget() end
 - InitTarget() start
 - InitTarget() end
 - ERROR: Failed to connect.
Could not establish a connection to target.
Connecting ...
 - Connecting via USB to probe/ programmer device 0
 - Probe/ Programmer firmware: J-Link EDU Mini V1 compiled Dec  7 2021 08:38:51
 - Device "NRF52833_XXAA" selected.
 - InitTarget() start
 - InitTarget() end
 - InitTarget() start
 - InitTarget() end
 - RESET (pin 15) high, but should be low. Please check target hardware.
 - Target interface speed: 200 kHz (Auto)
 - VTarget = 0.000V
 - ERROR: Failed to connect.
Could not establish a connection to target.
Connecting ...
 - Connecting via USB to probe/ programmer device 0
 - Probe/ Programmer firmware: J-Link EDU Mini V1 compiled Dec  7 2021 08:38:51
 - Device "NRF52833_XXAA" selected.
 - InitTarget() start
 - InitTarget() end
 - InitTarget() start
 - InitTarget() end
 - Target interface speed: 200 kHz (Auto)
 - VTarget = 3.182V
 - InitTarget() start
 - InitTarget() end
 - InitTarget() start
 - InitTarget() end
 - ERROR: Failed to connect.
Could not establish a connection to target.
```

rbaron, 2022-01-16:
@Meroje, another thing to try. You mentioned you connected the RST pad on the b-parasite to the J-Link. In my workflow, I do not connect the RST pin to the programmer. I manually briefly tie it to GND when I want to reset the b-parasite.

Try the following:
- Completely disconnect the b-parasite RST pad;
- Connect the b-parasite RST pad to GND;
- Run `nrfjprog --reset --log` - it should hang;
- Disconnect RST from GND;
- The `nrfprog` command should unblock and continue to execute;

Please let me know if that works.

Meroje, 2022-01-16:
Without RST the jlink bails immediately with low voltage

rbaron, 2022-01-16:
Did you try the sequence of actions I suggested? What happened? Did it initially hang?

If it shows a low voltage warning, I would try a different external power source for 3.3 V. And make sure to remove the battery then.

Meroje, 2022-01-16:
Turns out the swd ribbon was backward (pretty sure I did try at some point): it has to face "inward" on the jlink-edu board

rbaron, 2022-01-16:
Happy to know it's working now.

Meroje, 2022-01-16:
looks like it succeeded, will check the packets
```
nrfjprog -f nrf52 --program s140_nrf52_7.2.0_softdevice.hex --sectorerase
Parsing image file.
WARNING: A programming operation has been performed without --verify.
WARNING: Programming can fail without error.
nrfjprog -f nrf52 --program nrf52833_xxaa.hex --sectorerase
Parsing image file.
WARNING: A programming operation has been performed without --verify.
WARNING: Programming can fail without error.

nrfjprog -f nrf52 --reset
Applying system reset.
Run.
```
anyway, thanks for the tips and sorry for the confusion

a83r, 2022-04-28:
For future reference, on my j-link edu mini board the cable needed to plugged in like that:
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

Closed 2022-09-09.

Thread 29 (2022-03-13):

Negative Temperature Values

jhbruhn, 2022-03-13:
Wanting to use one left-over b-parasite to verify the temperature of my fridge, I noticed that the device does not transmit negative flawlessly (at least not to the ble_monitor solution). Is it a problem with the encoded packets or with the decoding?

As a plant-logging use-case, it might come in handy for plants which are on a balcony, or in the garden, although that specifically will not happen for my plants right now.

rbaron, 2022-03-13:
It seems like we:
1. Read the value out of the temp sensor as a signed 16 bit int [here](https://github.com/rbaron/b-parasite/blob/main/code/b-parasite/src/prst/shtc3.c#L61) (the [`temp_millicelcius`](https://github.com/rbaron/b-parasite/blob/main/code/b-parasite/src/prst/shtc3.h#L19) field is an `int16_t`)
2. But we [pass it to the `prst_ble_update_adv_data`](https://github.com/rbaron/b-parasite/blob/main/code/b-parasite/src/main.c#L80) that [expects an `uint16_t`](https://github.com/rbaron/b-parasite/blob/main/code/b-parasite/src/prst/ble.c#L163) and does some [bit-shifting](https://github.com/rbaron/b-parasite/blob/main/code/b-parasite/src/prst/ble.c#L173)
3. Then on the ESPHome bridge for example, I [handled it as an `uint16_t](https://github.com/esphome/esphome/blob/95a6715b2b3ebc30d31430b24beb888583a1f913/esphome/components/b_parasite/b_parasite.cpp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).

So I would say this is a bug. I believe a good solution would be to treat it as `int16_t` everywhere.

rbaron, 2022-03-13:
I did a quick test and it seems a quick workaround is just changing the decoding side to read the value into a signed `int16_t` instead:

```C
int main(void) {
  int16_t n_sig = -100;
  uint16_t n_unsig = n_sig;

  uint8_t encoded[2];
  encoded[0] = n_unsig >> 8;
  encoded[1] = n_unsig & 0xff;

  int16_t decoded = encoded[0] << 8 | encoded[1];

  // Prints -100.
  printf("%d\n", decoded);
}
```

But that invites another limitation. By using a signed 16-bit integer, we can only represent values in [−32768, +32767], which would map to °Celcius in +- 32.

The SHTC3 sensor is only accurate to 0.2 degrees Celcius, so encoding the temp in °Celcius * 1000 is unnecessary. We could instead encode is in °Celcius * 100, which would give us +- 327 °C range (this is exactly what I ended up doing [in another project](https://github.com/rbaron/sugarboat/blob/main/code/sugarboat/lib/sugarboat/sugarboat/ble.cpp#L183)).

I think this would warrant a bump in the [protocol version](https://github.com/rbaron/b-parasite/blob/main/code/b-parasite/config/prst_config.h#L31) and appropriate handling in the bridge code.

jhbruhn, 2022-03-13:
That sounds reasonable. I can make the appropriate PR to the ble_monitor HA component as soon as the new protocol version is defined.

On another note, while we are at it bumping the protocol version: There are BLE sensors which are using the same BLE-UUID to broadcast sensor information, specifically Xiaomi temperature sensors using the ATC firmware. The HA component currently differentiates between them using the length of the advertised message, which is obviously quite instable (see discussion https://github.com/custom-components/ble_monitor/pull/597#discussion_r776682917). One solution could be to add an identifier-byte somewhere into the message, perhaps to the end? Or we leave it as is and go for good luck... Alternatively we could switch to a new UUID as suggested in the comment thread of the referenced PR.

rbaron, 2022-03-13:
I think you answered the comment above very similarly to what I would. Initially I thought about encoding b-parasite's data into the "manufacturer specific data" section of the BLE advertisement packet. But for that I believe we'd need a registered [company ID](https://www.bluetooth.com/specifications/assigned-numbers/company-identifiers/). To avoid stepping on other people's toes, I instead opted for using a generic "environmental sensing UUID" (`0x181A `) and advertising the data in the service data section of the advertisement packet. In theory, we could have multiple service data sections.

The full BLE payload contains some useful info. By setting `PRST_BLE_DEBUG 1` (comments mine):
```
[ble] Encoded BLE adv packet
// flags section
[ble] 0x02  // length: 2 bytes
[ble] 0x01  // AD type 0x01; flags
[ble] 0x04
// Service data section
[ble] 0x15  // length: 0x15 bytes
[ble] 0x16  // AD type 0x16 - Service data
[ble] 0x1A  // This and next spell 0x181a (generic env. sensing 16-bit  UUID)
[ble] 0x18
[ble] 0x11  // First byte of our encoded data
[ble] 0x01
[ble] 0x0C
[ble] 0xF3
[ble] 0x5A
[ble] 0x6F
[ble] 0x3C
[ble] 0xAB
[ble] 0x00
[ble] 0x00
[ble] 0xF0  // Bytes 10-15 (inside the service data section) encode the MAC address itself (f0:ca:f0:ca:01:01)
[ble] 0xCA
[ble] 0xF0
[ble] 0xCA
[ble] 0x01
[ble] 0x01
[ble] 0x0A
[ble] 0xA9
// Name section.
[ble] 0x05  // length; 5 bytes
[ble] 0x09  // AD type 0x09 - name
[ble] 0x70  // This and next 4 bytes spell "prst"
[ble] 0x72
[ble] 0x73
[ble] 0x74
```

So we have a few possibilities:
1. Change from `0x181a` to something else. If we opt out of this generic env. sensing UUID, we'd probably have to use a 128 bit random UUID instead, which would make the whole adv. packet to exceed 31 bytes.
2. Use the extra info to differentiate b-parasite's advertisement from others. We could assert that the name in the adv. packet is equal to `"prst"` (this data is "outside" the service data section) and/or assert that bytes [10-15](https://github.com/rbaron/b-parasite/blob/main/code/b-parasite/src/prst/ble.c#L35) ("inside" the service data section) match the same MAC address as the the bridge sees[^1]

I think going for option 2 is a good compromise. LMK what you think.

[^1]: Having the MAC address inside the adv. packet seems redundant, but this is useful on macOS/iOS, which mostly don't give us the real MAC address of BLE peripherals

jhbruhn, 2022-03-13:
Checking the Mac bytes seems like a good idea as long as the Mac address matches the one provided. But at least for the HA plugin, that seems to be the case. I will implement that check as soon as the new format is finished.

Closed 2022-03-15.

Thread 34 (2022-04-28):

Minimal Case Design

drspangle, 2022-04-28:
I've been working on getting a bulk order of these sensors together for a home garden sensing project, and I've noticed that it might be possible to drastically reduce the amount of material used in the case without compromising the overall design. Is there any chance that someone with access to a 3d printer might want to take a crack at prototyping? I'm afraid I'm using an outsourcing service for mine, as I haven't got a printer.

drspangle, 2022-04-28:
Also, could anyone provide the original design files for the case? I can't import the STEP file into Fusion 360.

rbaron, 2022-04-28:
@drspangle did something recently change in Fusion 360? I am able to import the STEP file. I'm on version 2.0.11894 on macOS.

drspangle, 2022-04-28:
I'm not sure. I'm using version 2.0.12888 on Windows 10. When I try to import the STEP file it just hangs. I'll give it a try again today and see if I can't make it work.

rbaron, 2022-04-28:
@drspangle unfortunately I haven't ran any comparative tests for the humidity sensor with and without case. It would be interesting to come up with a case design that allows for better airflow in case this is an issue, while still protecting the board well.

For the illuminance sensor, if you want to use a case, my best suggestion would be to print it in a transparent material.

drspangle, 2022-04-28:
I think I've managed to get a few useful features implemented in the design, so that it doesn't have to be printed in a transparent material (but conformal coating, even the cheapest that can be found, would be recommended). This way the sensor should hold up better to splashes or even possibly outdoor use, provided it's used in less damp climates. You can find this in #35. I've asked other users in #3 to see if they can test out the design's printability (it should be as good as the original).

If anyone manages to get a print of the updated case out there and has some pictures, I'd be very grateful if you could share them here. Unfortunately I don't have access to a printer so I can't iterate on the case design very much. In an ideal world I'd like to see if I could incorporate some TPU gaskets on some of the inner surfaces so that a truly water resistant design would be possible, with minimal conformal coating.

JoelWise, 2022-04-28:
You might want to take some design inspiration from [weather station shields](ttps://www.google.com/search?q=weather+station+shield) to maintain temp and humidity accuracy.

I've also seen prints with a 1.75mm hole so a clear piece filament pressed and glued into it as a light pipe. Maybe a good idea for the light sensor and led.

drspangle, 2022-04-28:
> You might want to take some design inspiration from [weather station shields](https://www.google.com/search?q=weather+station+shield) to maintain temp and humidity accuracy.

This is a nice idea, but it runs a bit counter to my "reducing the amount of material" goal. To be honest I think the current interference-fit clamshell case design is a good one, the main areas where water infiltration is an issue is the programming pads and the battery connector, the rest (including the photoresistor) can be conformally coated and become effectively waterproof cheaply and easily. Because there needs to be gas exchange with the humidity sensor, the top of the board has to be exposed to the outside environment no matter what. Obviously the humidity sensor shouldn't be coated but I don't worry much about corrosion there.

I believe the programming pads are also less of an issue if they are solder-filled and coated on the top side, so they can be programmed from underneath on the uncoated side. A future hardware iteration might consider to put these as actual pads and only on the bottom, but this would require a fair bit of reworking and might not be worth doing. When conformally coated, the design of the case is mostly needed to prevent water from intruding on the bottom and into the battery clip, and that's where I think a TPU gasket could work to surround this portion of the board and keep moisture out.

I sure wish I had a 3d printer... I'm going to need to start thinking about buying one.

JoelWise, 2022-04-28:
Sounds cool. I'm all for having an improved case design! I'd love to have a 'hat' case that just securely slides on from the top that copies the design of weather sensor covers. Combined conformal coating it could work really nice!

hallsny, 2022-04-29:
I designed a  single piece thin wall l cap out of black ASA  that slides on over the upper section of the sensor.  The goal was to protect against water ingress for the upper section  via no additional case seams ( these will be outside 24/7  with automatic watering )  The bottom is open to allow some airflow, but the temp swings from sunlight limit the effectiveness of the temp/humidity measurement during the day. Even with a clear material to enable the illuminance measurement , I don't think  you could get an accurate temp measurement without significant airflow through the case. .

I'm reprinting a  few in white filament to  see if the temp performance is any better.
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

drspangle, 2022-04-29:
The humidity levels are dependent on temperature since I think it measures relative humidity, so that's why my updated design has air holes to promote freer gas exchange. It would be great to be able to more scientifically test the benefits and drawbacks in terms of these different case designs against one another.

JoelWise, 2022-05-02:
> I designed a single piece thin wall l cap out of black ASA that slides on over the upper section of the sensor. The goal was to protect against water ingress for the upper section via no additional case seams ( these will be outside 24/7 with automatic watering ) The bottom is open to allow some airflow, but the temp swings from sunlight limit the effectiveness of the temp/humidity measurement during the day. Even with a clear material to enable the illuminance measurement , I don't think you could get an accurate temp measurement without significant airflow through the case. .
>
> I'm reprinting a few in white filament to see if the temp performance is any better. 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

Can you share the design files? This would be a great base to build a pagoda-style cover that I suggested earlier.

hallsny, 2022-05-03:
I had a go at a higher airflow  printable cover. This should be printable upside-down as long as the printer is set up to bridge gaps and can print a 30 degree overhang.

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

JoelWise, 2022-05-03:
You beat me to it! Quite the upgrade! Printed in PETG. Good fit at default size but maybe be better at 101%.

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

drspangle, 2022-05-03:
Impressive work!

I take it that transparent PETG or similar material is required to make use of the photosensor?
Do you see a noticeable difference in the temp/humidity readings with this case versus without, or versus other case designs?

JoelWise, 2022-05-03:
I used PETG because my printer was setup for it. I would use white PLA but I don't have any at the moment!

I have found the photosensor to be useful only when the probe is monitoring small nursery plants since other larger plants' leaves shade the sensor. Ambient temp readings seem to be unaffected. Humidity reading are 10-15% above ambient but that is to be expected from a sensor that sits just inches above wet soil. Hah.

rbaron, 2022-05-04:
@hallsny that case looks gorgeous! Would you consider submitting a PR with it? Thank you!

JoelWise, 2022-05-05:
@hallsny I'm still interested in getting a copy of the slim case if possible. Thanks!

hallsny, 2022-05-05:
> @hallsny that case looks gorgeous! Would you consider submitting a PR with it? Thank you!
I would like to make some design update first and then can submit a PR.

 In general the difference  between the  high airflow case and my standard cover has been minimal in a side by side comparison. 0 is high airflow, 1 is standard, and 3 is a sensor with a normal cover in a  different shaded spot (low sun control). I may try opening up the sides to get more airflow through the cover.
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

> @hallsny I'm still interested in getting a copy of the slim case if possible. Thanks!

Here you go!
[soil sensor cover v4.zip](https://github.com/rbaron/b-parasite/files/8628927/soil.sensor.cover.v4.zip)

JoelWise, 2022-05-05:
Thanks!

Maybe humidity readings benefit more? The airflow case is still pretty slim and probably needs to extend far further to give the needed shade. Even then, the sensors are right at ground level which doesn't seem ideal if you expect accurate ambient readings. I'll share some of my own comparisons in a few days.

drspangle, 2022-05-05:
I'm starting to come to the conclusion that there are fundamental trade-offs between getting good light measurements, and the sensor's ability to read soil moisture and air humidity. In an ideal world, the light sensor would be someplace away from the device, but that would make it a piecemeal solution (perhaps a separate sensor solely for light/temperature/humidity readings is worth investigating).

The important question that is raised for me is, does the accuracy of the capacitive measurements for soil moisture have any dependency on temperature, air humidity, or light readings? If not, these sensors are no longer "must haves" on this platform and perhaps the size and design of the PCB and therefore the case could be simplified in a more specialized variant. A separate variant design that abandons the capacitive sensor and only has the other sensors could do that job a whole lot better. After all, there's no reason for everything to happen all at once on one device unless it really needs to, right? Thoughts?

JoelWise, 2022-05-05:
I always have viewed the other sensors as fun-to-have. They cost next to nothing to add and implement if you don't have a need to extreme accuracy. Moisture sensing ease and accuracy is #1. If anyone starts to have big redesign requirements then it's time to fork and roll your own.

drspangle, 2022-05-05:
I think that totally makes sense and is the same philosophy I have arrived at. The reason why I decided to look into this project was the capacitive sensor, the comms, and the prospect of long battery life -- not the other sensors.

Once I've brought up some of these boards and tested them out I'll probably take a crack at a fork for the sunlight and temperature measurements on a separate board, but it might prove unnecessary anyway. Another fork might be a dedicated actuator (irrigation, for example), built on the same foundation. Getting these to all work together is a software problem which is much simpler to solve and to version control than all this hardware waffling.

JoelWise, 2022-05-12:
Temp and humidity vs local weather service using the high airflow case. The probe is in a 5L pot and mostly shaded. Local weather is mostly cloudy, rainy, and cool.

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

jhbruhn, 2022-10-10:
Does someone have these (very nice!) case-files as an .stl file? I don't have access to Fusion 360. Preferably of course as a PR to this repository! :)

hubikj, 2022-12-05:
I recently played around with the high airflow case and it was too tight for me and the battery clip was getting in the way. So I made it slightly larger with bigger tolerances. You can check my results here: https://www.printables.com/model/306214-high-airflow-case-for-b-parasite

Closed 2023-02-12.

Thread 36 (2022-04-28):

Add pushbutton to design

JoelWise, 2022-04-28:
I think it would be useful to have a hardware de-bounced pushbutton added to the design. There appears to be room above the coin cell battery.

One idea is to have the sensor broadcast an additional data-point of 'dry set point'. When you press/hold the button the current moisture level is published. Then you could use this in automations to know when the plant needs to be watered. Or you could use this value in the sensor code and publish a binary true/false when the current moisture level falls below the set point.

drspangle, 2022-04-28:
I'm not sure what advantage this would have over a software based solution. There seemed to be some discussion about this in #21 and it might be worth revisiting this. My take is that the sensor shouldn't also be a user interface device, rather the orchestration should have this built in. The device running as the MQTT broker could just as easily serve the channel that lets you know when a specific sensor is out of range. On the other hand, having the ability to interact with the sensor would potentially be useful for calibration purposes, but I'm still a bit reluctant to suggest this given the limitations it imposes on the hardware's waterproofing and potentially the battery life.

JoelWise, 2022-04-28:
For a device who's primary function is to monitor moisture levels I think it's a big win to make it easier to set dry points. I already do this in software through home assistant but I can't help but notice home much time it takes to enable such a basic feature.

Of course it would be optional to even install the pushbutton just like the light sensor. And impact to battery level is zilch if you set the GPIO as a wake-up interrupt.

JoelWise, 2022-04-28:
[Capacitive touch sensing pad](https://infocenter.nordicsemi.com/index.jsp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) but it would be hard to use if you use a case. Or a [small reed switch ](https://www.digikey.com/short/bm0020d5)activated by strong magnet.

Though, I think a normal push button would be fine for most applications! Not everyone expects their sensors to make it through a hurricane. :)

drspangle, 2022-04-28:
The problem with ordinary pushbuttons is that if they start to intermittently short when they get wet, even a debouncing circuit or software debouncing will not be effective to prevent false buttonpresses and that can cause serious problems if the button does something important like setting calibration modes and things of that sort. I do like the idea of the reed switch a lot.

How do you envision the dry set point would work?

JoelWise, 2022-04-28:
That makes sense. It's pretty simple to add some pads for an optional button and you could design the footprint to be compatible with more than one button type (push, reed, capacitive). And the button could be disabled altogether during compile if someone is that worried about false presses. I know this adds even more complexity to the project so it's OK if doesn't happen! I'm not doing the work after all!

For me, I imagine a press and hold (5 seconds?) then the system would record the current moisture value and maybe blink the led (5 times) as feedback that it worked. This value could be exposed in broadcast with the other real time temp/hum/lux/moisture data. Every broadcast would share the set dry point even if it hasn't been changed since last broadcast. Then this value could be used as an entity in home assistant to trigger automations if the real time moisture level falls below the dry set point. You could also do this comparison in the probe software itself and have a true/false bit in the broadcast that represents Needs Watering. Aaaannd home assistant blueprints could make setting up the automations even easier. :)

drspangle, 2022-05-01:
I think it's a neat idea. I'm not sure there are any pins broken out that we could add a switch to, but I get the impression that this could potentially be a useful addition.

Closed 2023-03-30.

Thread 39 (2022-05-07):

Mosfet instead of Q2 and Q3 bipolar?

pit34, 2022-05-07:
Hello,

I ask myself why does Q2 and Q3 are bipolar tranistor and not mosfet ?
There is an explanation of operation here :
https://wemakethings.net/2012/09/26/capacitance_measurement/
But not why bipolar instead of mosfet to discharge the capacitor.

Thanks

rbaron, 2022-05-07:
Hi @pit34,

I think a MOSFET would work as well, possibly with fewer passives. But if I were to rework the electronics, I would probably go with an Op-Amp instead of rolling out my own amplifier with discrete transistors.

pit34, 2022-05-07:
Thanks @rbaron
Can you tell me more about your Op-Amp solution?
I can't see why a mosfet after R1, acting like a simple closed switch when square wave is low, are not the simpliest and "best" solution ? Why using amplifier?
Thanks in advance

rbaron, 2022-05-07:
There are two things here:
- Q3 is already a p-channel MOSFET. It's used to protect the circuit from sticking the battery in the wrong way (reverse polarity protection);
- Q1 & Q2 (that's Q2 and Q3 in the article you linked), are used to improve the low-pass filter & integrator, so we get a bigger swing on the output (the article explains why)

So the circuit works without Q1 and Q2, but it has small dynamic range. One idea is to use an op-amp on the output to improve this dynamic range. This has some advantages (e.g.: more linear, less power, simpler circuit) and some disadvantages (we also amplify the noise). I'm not 100% sure this is better, but it's something that I would like to experiment with. I hope this answers your question.

pit34, 2022-05-07:
My apologies, I haven't seen the differences between the articles and your schematic... I though it was a fork. Sorry.
I understand your Op-Amp solution, and why Q1 and Q2 are used to improve dynamic range.
But I still not understand why you too use bipolar for your Q1 and Q2 instead of a p-mosfet. Sorry if this is a stupid question..

Another question, why using a "FAST_DISCH_EN" signal instead of just connecting this to "PWM" signal ?

rbaron, 2022-05-07:
@pit34 you can find many resources on BJTs vs MOSFET on the web. In this particular case like I said, it doesn't matter too much - either should work I believe.

The FAST_DISCH_EN signal is essentially 3.3V, but it's software enabled so it doesn't drain the battery during deep sleep. The signal on the base of Q1 (Q3 in the article) is still the PWM signal.

pit34, 2022-05-07:
Thanks for your reply. I understand this part now ;-)

Closed 2022-05-07.

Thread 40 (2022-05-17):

Mistake in wiki https://github.com/rbaron/b-parasite/wiki/How-to-Program#using-the-swd-power-supply

tispokes, 2022-05-17:
GND is listed twice. Should be Vcc I guess :-)
@ https://github.com/rbaron/b-parasite/wiki/How-to-Program#using-the-swd-power-supply

rbaron, 2022-05-18:
Tks @tispokes. It's fixed now.

Closed 2022-05-18.

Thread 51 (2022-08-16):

Flashing Issue

binaryhellstorm, 2022-08-16:
I've been trying to flash a couple of these PCB's and I am getting this error on one of them

user@box:~/Desktop/b-parasite/b-parasite-main/code/b-parasite$ make flash_softdevice
Flashing: s140_nrf52_7.2.0_softdevice.hex
nrfjprog -f nrf52 --program /home/user/Desktop/b-parasite/nRF5_SDK_17.0.2_d674dde/components/softdevice/s140/hex/s140_nrf52_7.2.0_softdevice.hex --sectorerase
Failed to read device memories.
ERROR: JLinkARM DLL reported an error. Try again. If error condition
ERROR: persists, run the same command again with argument --log, contact Nordic
ERROR: Semiconductor and provide the generated log.log file to them.
NOTE: For additional output, try running again with logging enabled (--log).
NOTE: Any generated log error messages will be displayed.
make: *** [Makefile:316: flash_softdevice] Error 33

Not sure if I maybe cooked my Bluetooth module when I used the hot air reflow station on it, have some more on order but wasn't sure if I was missing something silly in the meantime.

chucknorris101, 2022-08-16:
If it helps, I have been assembling with a hot air gun as well and have no issues.

From my poking around with alternative programmers, and with the jlink on the DK working now, if you are getting this message, it at least knows it is an NRF (not cooked) - not being able to read the memories may be due to the chip being locked. Try a nrfjprog -f NRF52 --recover first then the make commands as this should remove the chip lock

binaryhellstorm, 2022-08-16:
Ok, gave that a shot and get this

user@box:~/Desktop/b-parasite/b-parasite-main/code/b-parasite$ nrfjprog -f NRF52 --recover
Recovering device. This operation might take 30s.
ERROR: Recover failed. Please make sure that the correct device family is given
ERROR: and try again.
NOTE: For additional output, try running again with logging enabled (--log).
NOTE: Any generated log error messages will be displayed.

chucknorris101, 2022-08-16:
hm - if you run recover cmd with the -log or --log it should give you a log file to poke at to see what is hanging it up, or same thing with the original command.

I still dont think its cooked as it would say that its not an NRF in the earlier command, i would think. I have one board that is still giving me issues in recovery as well - i think its an issue with the soldering, so my plan is to reflow it at some point and retry. I may also poke around with the ESP32 SWD flasher to see if it recognizes it as NRF as well which could be another way to confirm its not cooked.

binaryhellstorm, 2022-08-16:
I think you're right that it's a software issue. When I run with the --log flag I get

[error]: [SeggerBackend] - JLinkARM.dll reported "-1", "An unknown error.".

Which is weird as I'm on Ubuntu so there shouldn't be DLL's being used at all.

schejbity, 2022-08-16:
I had same issue.
Solved with "make flash_loop"
Look in to the wiki...

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

binaryhellstorm, 2022-08-16:
I did see the note in the wiki but it seemed to indicate that was for previously flashed boards, so I ignored it.

I gave that a shot though and I get this output:
nrfjprog -f nrf52 --program _build/nrf52840_xxaa.hex --sectorerase
ERROR: Unable to connect to a debugger.
ERROR: JLinkARM DLL reported an error. Try again. If error condition
ERROR: persists, run the same command again with argument --log, contact Nordic
ERROR: Semiconductor and provide the generated log.log file to them.
NOTE: For additional output, try running again with logging enabled (--log).
NOTE: Any generated log error messages will be displayed.
make[1]: *** [Makefile:310: flash] Error 33
make[1]: Leaving directory '/home/user/Desktop/b-parasite/b-parasite-main/code/b-parasite'
make[1]: Entering directory '/home/user/Desktop/b-parasite/b-parasite-main/code/b-parasite'
DONE nrf52840_xxaa
Flashing: _build/nrf52840_xxaa.hex
nrfjprog -f nrf52 --program _build/nrf52840_xxaa.hex --sectorerase
^Cmake[1]: *** [Makefile:310: flash] Interrupt
make: *** [Makefile:329: flash_loop] Interrupt

When I pull the RST line to ground the output stops until it's disconnected. Tried it a few times, started the command, pulled RST to ground for a second or two, sadly no change.

binaryhellstorm, 2022-08-17:
Got it to work on at least one unit. I think my crap soldering was to blame, in fairness this is my first time doing any sort of SMT soldering that wasn't more in the warranty violating arena.

Thanks everyone for the suggestions and putting up with my dumb questions.

Closed 2022-08-17.

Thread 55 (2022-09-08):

Consider redesign board for CR2477 or CR2450 battery instead of CR2032?

Hedda, 2022-09-08:
Suggest re-design board with battery-clip/battery-holder/battery-retainer for CR2450 or CR2477 batteries instead of CR2032 batteries?

* CR2477 is 24 x 7.7 mm in size and usually has about 1000 mAh of capacity on average.
* CR2450 is 24 x 5.0 mm in size and usually has about 550 mAh of capacity on average.
* CR2032 is only 20 x 3.2 mm (coin cell size) but only has 200 mAh average capacity.

Alternative universal solder pads supporting fitting battery-clips/battery-holders/battery-retainers for either CR2477, CR2450, or CR2032?

I think that it might be possible to find a cleverly designed battery-clip/battery-holder/battery-retainer for CR2477 that could even be able to hold either a CR2477 or a CR2450 or even two CR2032 batteries stacked on top of each other, or what do you think?

Example:

MYOUNG MY-2477-02 (Mfr. Part # MY-2477-02 LCSC Part # C2979175)
https://lcsc.com/product-detail/Battery-Connectors_MYOUNG-MY-2477-02_C2979175.html

MYOUNG MY-2477-01 (Mfr. Part # MY-2477-01 LCSC Part # C2979173)
https://lcsc.com/product-detail/Battery-Connectors_MYOUNG-MY-2477-01_C2979173.html

MYOUNG MY-2450-01 (Mfr. Part # MY-2450-01 LCSC Part # C964845)
https://lcsc.com/product-detail/Battery-Connectors_MYOUNG-MY-2450-01_C964845.html

Reference:

https://jeelabs.org/2015/07/29/could-a-coin-cell-be-enough/index.html

 PS: I personally hate to replace batteries so really looking to get a large battery capacity and a long time between replacements.

rbaron, 2022-09-09:
I'm fairly happy with the CR2032. They're cheap, small, available everywhere and can be made to theoretically last a over couple of years.

You are of course free (under CC BY-SA) to redesign the board to better suit your needs.

Hedda, 2022-09-09:
OK, but FYI, CR2450 and CR2477 are also very inexpensive and commonly available almost everywhere today, so a 10-pack of either CR2450 or CR2477 costs less than $10 US-dollar now so please do not let price per battery play a major role in your decision, see example:

https://www.google.com/search?q=CR2450&tbm=shop

https://www.google.com/search?q=CR2477&tbm=shop

https://www.amazon.com/s?k=CR2450

https://www.amazon.com/s?k=CR2477

https://www.amazon.de/s?k=CR2450

https://www.amazon.de/s?k=CR2477

nielsfaber, 2022-11-21:
I agree with the proposal of @Hedda

CR2032 clip footprint (the one that is recommended):
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

CR2450 clip footprint (random one from aliexpress):
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

By increasing the spacing between the solder pads for the sides to approx. 25mm, and leaving some clearance next to the pads for the bigger clip, it would allow both versions to be soldered.

I would like to see this updated in the project.
Users can choose which version they want to make, only the case would be different (CR2450 battery is 24.5mm wide, so will be wider than the PCB).

(I don't have+know KiCad otherwise I could submit this change myself)

Closed 2022-09-09.

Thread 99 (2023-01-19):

Connect to home assistant

sam632, 2023-01-19:
Hi, I downloaded this repo and flashed it to a b-parasite using the ESP32 method with the BLE sample with `CONFIG_PRST_BLE_ENCODING_BTHOME_V2=y` added to the prj.conf file and all went well. I get the flashing red light when I put the battery in and after some time (overnight) it appeared in home assistant. Then later the entity appeared and it is sending data to home assistant but its constantly displayed as "Unavailable" due to the device sleeping.

Is there a way to make home assistant display the last available data and the update accordingly (every 10 mins I believe is the default but it seems to be random at the moment?)?

Thanks in advance.

jhbruhn, 2023-01-25:
I believe this is related to #98

rbaron, 2023-01-25:
@sam632 are you using a proxy or talking to HA directly? How far away is it?

sam632, 2023-01-26:
> @sam632 are you using a proxy or talking to HA directly? How far away is it?

talking directly to HA. It is currently next to the RPI4 but I will buy a bluetooth antenna for the RPI as the range is terrible.

RobertLukan, 2023-01-31:
Which nRF chip are you using ? I have replaced ceramic antenna with 1mm thick wire and there is a tremendous improvement. There is an open issue about this topic. You might want to consider the same if you are facing signal issues.

sam632, 2023-02-01:
I'm using the E732G4M08S1C. It has a ceramic antenna so I will look into that, thanks!

rbaron, 2023-03-21:
Closing due to inactivity. Note that #98 may have fixed the issue. Please feel free to report back.

Closed 2023-03-21.

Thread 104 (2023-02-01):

Values change each time I move the sensor

Ulrar, 2023-02-01:
Hi,

I've had one board in a plant for a few months, and it's been reporting around 90% pretty reliably since, never really going down.

A few weeks ago I tried moving it to another plant, and it reported 90%, but started slowly trending down (with jumps by one or two percent either way on each reading, but trending down overall). It was down to around 85% the other day when I decided to take it out, and update the firmware with the new ble samples format.

I went with BTHome v2, and since it's been very spotty :
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
Because I went from BTHome 1 to 2 the statistics weren't compatible so I dropped all the old data, this is what I got since.

Going unavailable and unpredictable reporting periods aren't great, but my real issue here is the numbers it's reporting. It went from ~85% before I flashed it down to 30, moved it and it went to 0, moved it again and it's now up to around 10, trending up. I'm only moving the board by a few centimeters each time.

Am I doing this wrong, and how do I go about placing these correctly ? I have no idea what the real number is.

I did coat the board, although it might not be done well.
Thanks

rbaron, 2023-02-01:
Hi @Ulrar,

We've been looking into the BTHomeV2 data gaps issue in #98, so I'll focus on the numbers you're seeing. It's somewhat usual to see some interesting patterns (e.g.: #50, #2, [this comment](https://github.com/rbaron/b-parasite/issues/19#issuecomment-1261122074)), specially during the first couple of watering cycles. The jumps you're seeing when you move the sensor are likely due to:
1. Moving the sensor creates some air pockets between the sensor and the ground. These capacitive sensors must be in close contact with the soil for a reliable reading. You can try a quick experiment by holding the pads tightly with your hands and then removing some pressure. You'll see some significant difference in readings.
2. My mental model of the soil is close to a sponge. For example, when watering it, it takes naturally some time for the moisture to become close to uniform in the pot and the readings to converge. I speculate that there's a local disturbance when you move it, and it takes some time to converge back.
3. It seems like there is some "capillarity" effect in the surface of the sensor, in a way that it first "saturates" with water before setting into a more stable mode.

Whenever I place/replace a sensor, I try to stick it in a new place to avoid 1 and I make sure to compact the soil around it. If I'm testing something I will put some water around it to help it accommodate itself in the soil too.

Ulrar, 2023-02-02:
Thanks for the answer, that makes sense !

I hadn't actually realized there's a Zigbee firmware now, I do have a lot of Zigbee devices so I just flashed that. Looks good so far, but I'll keep an eye on it.

I took your advice hopefully correctly and compated the soil a bit, put a little bit of water and planted the sensor in moist compacted soil. It immediately started reporting 84%, which at least sounds about right.
I'll monitor that over the next few days and see how it goes, thanks for the advice !

rbaron, 2023-02-09:
@Ulrar, we're tracking the issue with HA marking the sensor as unavailable in #98. It seems like there was a bug with HA - see https://github.com/rbaron/b-parasite/issues/98#issuecomment-1424645478.

I'll close the issue for now, tks!

Closed 2023-02-09.

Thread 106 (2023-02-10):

Illuminance values incorrect

HartD92, 2023-02-10:
Using Zibee build, connected to Home Assistant via ZHA. One Sensor has never reported anything but 1 lux, and another cycles between exactly 1 lux, 17 lux, and 41 lux, with no other values ever reported.

I confirmed that the luminance sensor was correctly positioned on the pick/place order, and the programming with bluepill seemed to work correctly. All other values report back roughly what I'd expect.

rbaron, 2023-02-12:
I only have two b-parasites running the Zigbee firmware, but they seem to be okay for illuminance. Here's a recent 3-day sammple:

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

But I also have a board with a known faulty phototransistor (whose orientation-correcting surgery I botched, destroying it) that curiously outputs the a similar set of values in {1, 17, 41, 59}, independent of actual light shining on it:

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

This data suggests that you have a fault/wrongly orientated phototransistor. Did you follow the [Q4 orientation guide in the Wiki](https://github.com/rbaron/b-parasite/wiki/How-to-order:-PCB-fabrication-and-SMT-assembly)? For 1.2.0 boards the analogy remains: collector goes by the silkscreen dot.

Here's what it looks like upclose in a 1.2.0 board:

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

HartD92, 2023-02-12:
This was the confirmed production file, showing the Collector oriented on the left of the PCB, as noted in Issue #42
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

And this is the output I get on the device that outputs 1,17,41:
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

rbaron, 2023-02-12:
The nRF52 footprint seems different from the one in the repo, but that shouldn't matter. Which nRF52 module are you using? Did you solder them yourself? It could be a hardware issue. I would 1. double check the solder joints, specially these two pads:

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

and 2. Run the ble sample with:
```
CONFIG_PRST_SLEEP_DURATION_SEC=1
CONFIG_PRSTLIB_LOG_LEVEL_DBG=y
```

And watch the debugging messages. You should see stuff like this in the RTT terminal:
```
[00:03:00.023,620] <dbg> adc: prst_adc_photo_read: Read phototransistor: 225 lx | 0.04 V
```

HartD92, 2023-02-12:
I used the E73-2G4M08S1CX, which I saw others had used. Afaik it's the same module, just with an antenna port instead of a built-in ceramic antenna. I had it placed/soldered by JLCPBC, I didn't do it myself. The solder joints all look fine. I need to pick up some more CR2032s, but I'll do that and follow up with the results of the BLE w/ debug.

rbaron, 2023-02-12:
Meanwhile you can also double check the orientation by comparing your board with the pic I sent in https://github.com/rbaron/b-parasite/issues/106#issuecomment-1427042467. The inner darker square should be slightly shifted do the left in your case:

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

HartD92, 2023-02-12:
Yeah, I checked, it looks correct like the picture you sent.

HartD92, 2023-02-12:
I put batteries in two more, and those are reporting correct illuminance values. I will reflash one of the ones that's having trouble with the BLE fw with debug still, to see what exactly it's reporting with that firmware still, to see what it reports back, but at least it's definitely not a problem with the part placement/circuits.

One interesting thing that DID turn up here, one of these devices is reporting that it's battery powered, and with a battery % diagnostic:
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
All of the rest of them report back that they are mains powered, and therefore have no battery %:
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
 Which one is working as intended?

rbaron, 2023-02-13:
> it's definitely not a problem with the part placement/circuits

If 2 out of 3 boards work with the exact same firmware, I stand by my original guess that it's a hardware issue. The analog pin sampling the phototransistor is likely just reading ground through R10. It's unlikely that logging will print something other than ~0 V. Could be a bad solder joint (the two joints around Q4 and between Q4 and the nRF module are the bigger suspects), or a faulty phototransistor.

> Which one is working as intended?

We [configure our power config cluster](https://github.com/rbaron/b-parasite/blob/main/code/nrf-connect/samples/zigbee/src/main.c#L67) with a 1-battery cell, so I'd expect to see that.

Closed 2023-02-26.

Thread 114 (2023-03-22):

Unable to reprogram an already programmed b-parasite

cloyd1815, 2023-03-22:
I followed along with discussion #105. I got my boards the other day and I'm just getting around to programming. I got two boards soldered up with battery clips. I programmed one with BLE to test out and one with zigbee. When I go to reflash the BLE one (or the zigee) I get an error from nrfjprog commands. Any command I run shows `[error] [SeggerBackend] - JLinkARM.dll reported "-1", "An unknown error.".`. Is it possible to reprogram these or are they one and done? Am I doing something wrong?

The commands I'm trying are
`nrfjprog --family NRF52 --recover`
`nrfjprog -f nrf52 --program zephyr.hex --sectorerase`

RobertLukan, 2023-03-22:
I faced this issue also. Initially, I did not have any problems with flashing boards with RPI and OpenOCD, but I was unable to get RTT debug running. So I decided to purchase nrf dev kit. At this moment I started getting problems. I got this unknown error and I just could not understand it why for a couple of days. I decided to revert back to RPI and everything was ok again. In between, I decided to provide power from RPI and not for dev kit and have only Data and CLK connected to dev kit. Try to power your board by using another 3,3V source, but make sure to have GND connected to external source and dev kit.

cloyd1815, 2023-03-22:
I can try that, do you think trying to program while the battery is in instead would work too?

I forgot to mention in my post that I am using the same programmer as the #105 post. Which is [this ](https://www.amazon.com/gp/product/B07V2CKG19/)one.

cloyd1815, 2023-03-22:
I successfully re-flashed one with the battery. I removed the pin from my 3.3v on my pogo pin clip and soldered on a battery to a new board and then flashed the zigbee hex to it. I set it up in HA then connected it again and ran `nrfjprog --family NRF52 --recover` without error and flashed it again with the zigbee hex without error.

rbaron, 2023-03-23:
Thanks for helping out @RobertLukan.

@cloyd1815 since you managed to fix it, I'll close the issue. Please feel free to reopen.

Closed 2023-03-23.

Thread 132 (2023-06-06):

Non fuctional JLCPCB pcbs or other issues

azgael, 2023-06-06:
Dear All
Does anyone else experienced the board not to even blink the blinky example after successful programing.
I have assembled one first board b-parasite version 2.0.0 and it worked still it behaves a bit strange, worked for a couple of days and then after I removed from the vase earth to check its assembly it stop sending data to home assistant.
Meanwhile I have tried to assemble another 7 boards but I am facing a bigger problem, basically I can program successfully all of them still the led still does not blink (Blinky and Zigbee example), I have experience soldering and reviewed the board for shorts and cold solders and found none. now I start doubt from the radio modules with NRF52833, still I found very strange to have 7 failures in 8 radios.
I just wonder if any one had similar problems?
Is it possible to have a mistaken passive and preventing the board to start, by looking at the schematics seams too simple fur such think to happen, anyway?
I have order the pcbs electrically tested but is it possible that they get damaged during soldering(hummmmm stupid question I am sure) or defect from the factory?

Sorry for the useless topics but I am totally desperate with 7 b-parasites not working and one that does when it feels like!
Thanks in advance,
BR
Azgael

rbaron, 2023-06-06:
Hi Azgael,

I would be very surprised if all 8 boards are defective due to a production error. It's more likely either an error in the submission (e.g.: wrong orientation of some component), manual soldering error (if you assembled the nRF module manually), or (hopefully!) some software config error.

Here's what I would do first:
1. Double check you're selecting both the correct board version _and_ revision when building the code in VSCode
2. Try to get some log out of it using the VSCode extension - [this is how I do it](https://nrfconnect.github.io/vscode-nrf-connect/reference/ui_sidebar_connected_devices.html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)

azgael, 2023-06-06:
Dear rbaron
First of all thanks a lot for sharing all this work, being available for the community is just impressive!!
Second thank you your quick reply, so I further explain, I have experience in soldering fine pitch electronica manually (down to coax cables on OV6948 chips :)) using our office professional equipment. With this in the back of my mind , I have ordered only the pcb's and fully populate them manually , including the HT Sensirion chip with the under path (done it before!).
So I have manually fully solder the first semi working board, since it was working I have assembly additionally 6 boards which I have done by populate them manually excluding the battery contact and the rf module and re-flow them after in a company mini oven. After that I have check for shorts and cold solders, retouched and all looked clean. Them I  solder the RF module and the battery contact, So I have plug them to my segger mini edu and was able to program all of them(Zigbee example), still nothing waked up. Reviewed everything including orientation.
After I have solder one additional one more fully by hand extra carefully with components (thinking the re-flow may have damaged the board) funny is it programed and blinked for a period that the led become lower and off again, did not wake up again!!
Just this late afternoon I have reviewed the pcb layout and look more in detail about this underpad vias for the ground on pin 5 of the rf module, Hummm, (thought is possible that I have a week ground???) I pick one of the never working ones and soldered this pin directly to the ground pad and also a ground plane on the back of the pcb, funny is it started to blink and could catch it in the Zigbee2mqtt, after some minutes it lost communication, now has the same behavior as the first one, works when it feels like!
I will spend some more time with it tomorrow, probably to reinforce all vias with air-wires I suspect that the fact that the vias are relatively thin for such a thick 2 layer pcb and the fact that they are under the soldering pad they may crack due to the iron heat applied on the radio module pads, this connection might be week for the full current drain of the module specially in the power up. So now my plan is to reinforce all the via connections. Hopefully I can avoid the hours of oscilloscope!

As for the debug of the code I confess I have tried to connect the console but don't get anything out (not much time spent) additionally i have serious trouble on debug zephyr code using the nrf sdk with VScode, still I will try tomorrow to connect to get the log, still on my system I have no vcom only the segger edu mini RTT connection.
Am I suppose to get anything on this RTT port, if so should I configure the baud-rate etc of it ?

The board Version I have selected is the 2.0.0 as my pcb's all looks fine on compiling (some errors and warnings on vscode but a clean built) !

Will keep you posted if this wiring works we could benefit from some review on the layout.

Thank you once again!!
Azgael

rbaron, 2023-06-07:
> Am I suppose to get anything on this RTT port, if so should I configure the baud-rate etc of it ?

The defaults should work. I usually just click the RTT button in the extension. More rarely I also use the `JLinkRTTLogger` CLI from the terminal. (I also have no VCOM option, we don't define a UART logger)

azgael, 2023-06-09:
Hi rbaron
Thanks for the feedback, I have check the logger via rtt and worked fine helping me to understand that on this misbehavior boards I had some issues with the HT sensor, again traced down to vias issues.

Trying to debug the issue I have looked for shorts and bad soldering manually retouching all contacts on all boards but still did not recover the boards, after I have decided to assemble one board fully by hand (no reflow) and I was able to program it and it started to work normally. To further debug I have pick one of the previous boards and rewire all critical via pads (under-pad vias) and found out that the board begin to work properly.
Concluding that there is an issue with the via connection between bottom and top layer, (in fact the via are 200um diameter not necessary small for breakage) following I have tested the electrical connections on non populated pcbs and the connection is present but it tends to break past the soldering process using standard re-flow temperature profile with peak temperature at 280C.
Basically seams that there is thinner copper layer than expected the 18um on the vias, I would need xray to measure it so I just quit further investigation. Unfortunately I seams I have received pcbs that were miss processed by the manufacturer, I have presented a complain and they request me the return of the boards for further investigate, due to the cost of the pcb's the shipment would be more expensive than a new lot, so I have decided not to return them.

Probably when you order the complete assembled boards from the manufacturer this issues do not appear still seams to me that some review on the pcb design is recommendable.

So for my next order I will remake the layout by removing under-pad vias, probably increase via diameter (there is enough space!) and track wide, just in case!!

 Normally I use Altium but I will try to work with kicad, if I manage I will be happy to share the files just in case you want an updated version 2.0.1 :).

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

ps.: Ugly but it worked!!!

azgael, 2023-06-09:
Concluded that was a defect PCB lot, proposed some changes on pcb layout, I will review and reorder the pcbs.
Thank you a lot Rbaron for the debug instructions and further support!!
BR
Azgael

Closed 2023-06-09.

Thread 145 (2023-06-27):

Zigbee code does not update value

AlbanDurrheimer, 2023-06-27:
Hello,

I have some b-parasite boards and several it does not update value (all sensors included) after some hours (almost every 2 days).
To fix the problem, I have to restart the device by removing and reinserting the battery.

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

Does this happen to other people? And do you have a solution?

### Additional information:

B-Parasite Board: 1.2.0
Firmware: latest firmware in main branch (f6b46000448239a9e5288051953c34e94e617c5f)
Coordinator: Home Assistant ([2023.6.2](https://github.com/home-assistant/core/releases/tag/2023.6.2)) with Zigbee2MQTT ([1.31.2](https://github.com/Koenkk/zigbee2mqtt/releases/tag/1.31.2))

rbaron, 2023-06-27:
@AlbanDurrheimer this is unfortunately an open issue with the ZigBee sample. Recent attempts to fix and discussions are in #126, #130 and more recently on #136. We're having a hard time debugging this, as the problem sometimes happen in a few days, a few weeks, and on the other hand some of my sensors are running for multiple months without issues.

Do you have multiple b-parasites running ZigBee? Do they all experience this issue around the same time?

AlbanDurrheimer, 2023-06-27:
Thank you @rbaron for your reply.

Yes, I have three cards at the moment (but more are being soldered) with zigbee firmware. And no, they don't produce the problem at the same time, I have one that currently produces the problem every day or so and the others have also already produced the error, but for the moment it's calmed down.

If I can help you find the source of this problem, please don't hesitate to let me know and explain how to proceed.

rbaron, 2023-06-27:
Thanks @AlbanDurrheimer. Were the batteries drained from any of the sensors after the problem occurred? Or did just resetting them fix it?

AlbanDurrheimer, 2023-06-27:
> Thanks @AlbanDurrheimer. Were the batteries drained from any of the sensors after the problem occurred? Or did just resetting them fix it?

@rbaron I haven't had any drained batteries, just one that I noticed was half empty, but I wonder if I'd used it before, so I don't know if it's related... In my case, a simple restart (removing-inserting the battery only once) is enough to get the sensor working again for at least 1 day.

AlbanDurrheimer, 2023-06-28:
It's happened again, and this time neither the reboot nor the factory reset was able to update the sensors values. The module just reconnected to the coordinator, but didn't send back any information from the sensors. I had to run a reconfiguration from Zigbee2MQTT to get the sensor to update again.

Regressor, 2023-07-05:
> It's happened again, and this time neither the reboot nor the factory reset was able to update the sensors values. The module just reconnected to the coordinator, but didn't send back any information from the sensors. I had to run a reconfiguration from Zigbee2MQTT to get the sensor to update again.

I've seen this behaviour with smart plug - it just stops sending measurements and the only way to fix this was a reconfiguration. It looks like this is a zigbee2mqtt problem not b-parasite.

AlbanDurrheimer, 2023-07-05:
> > It's happened again, and this time neither the reboot nor the factory reset was able to update the sensors values. The module just reconnected to the coordinator, but didn't send back any information from the sensors. I had to run a reconfiguration from Zigbee2MQTT to get the sensor to update again.
>
> I've seen this behaviour with smart plug - it just stops sending measurements and the only way to fix this was a reconfiguration. It looks like this is a zigbee2mqtt problem not b-parasite.

Thanks for your feedback, I'll test this the next time it produces the problem.

AlbanDurrheimer, 2023-07-10:
I carried out several tests and here are the findings:

### 1. Send a reconfiguration
 > I've seen this behaviour with smart plug - it just stops sending measurements and the only way to fix this was a reconfiguration. It looks like this is a zigbee2mqtt problem not b-parasite.

The board does not respond to the command (timeout).

### 2. Restart Zigbee2MQTT
No new data sent by the board.

### 3. Restart the b-parasite board
The board joins the Zigbee network again, but no data is sent back.

### 4. Restart the b-parasite board with Zigbee2MQTT enable joining
The board joins the Zigbee network again, but no data is sent back.

### 5. Reset the b-parasite board
The board does not join the Zigbee network.

### 6. Reset the b-parasite board with Zigbee2MQTT enable joining
The board joins the Zigbee network, but no data is sent back.

### 7. Remove the devices to Zigbee2MQTT network then enable joining
The board joins the Zigbee network, but no data is sent back.

### 8. Remove the devices to Zigbee2MQTT network and reset the board then enable joining
The board joins the Zigbee network, but no data is sent back.

### 9. Move the plant to the same room as the coordinator

Once it was working again, I moved the board to the same room as the coordinator (over a weekend). There was no problem until I moved the board back to its old location, where it crashed in less than 12 hours. (I should point out that in both rooms, the signal is greater than 200 lqi).

### 10. Conclusion

To conclude, I can no longer remove the error from my board. And yet, it still responds to commands such as `genBasic/hwVersion`.

rbaron, 2023-07-10:
Thanks for the detailed testing @AlbanDurrheimer. It's odd that the board doesn't work after a reboot. This I haven't experienced so far. Could it be some hardware issue when reading the sensors? Maybe some debug logging could shed some light into it. Did you experience it with multiple boards?

There's also #146 that fixes a bunch of issues with the zigbee firmware. It's too early to tell if they're gonna help in the long term, but so far I'm running it for 2w with no issues.

AlbanDurrheimer, 2023-07-10:
This is the same card with which I'd encountered problems earlier. Every time it crashed, a reboot or reset was enough to get it working again. It also worked all last weekend indoors, then I moved the plant outside for a night, then nothing

Closed 2023-07-23.

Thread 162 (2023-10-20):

Questions from a novice

Timmiej93, 2023-10-20:
I stumbled upon this project somewhere, and it looks to be exactly what I need. I've done some custom PCB projects before (QuinLED for example), but with this there seems to be a lot less guidance. Although I know the basics about most things here, I don't know which is the right option. I also don't know anything about PCB assembly by the factory, so here's a few questions from my side. I'd be happy to convert it into a Wiki article afterwards to help others in the future.

### The very first questions
**How active is this project?**
It doesn't seem like there has been a lot of activity recently. Is that because the project has reached its final form and doesn't need any changes anymore, or ahs it been abandoned?

**Software**
I see there's different software options available. It seems like the bottom three (blinky, soil_read_loop and input) are mainly debugging/development firmwares, and the BLE and Zigbee options are for production. Given my experience with BT and Zigbee in my current setup, I'd MUCH prefer Zigbee on these devices. However, it's not clear to me if the difference between Zigbee and BLE is purely in firmware, or if there's a hardware change too.
**Q:** Do the BLE and Zigbee versions require different hardware?
**Q:** Since I'm not planning to use BT, is there a (cheaper) alternative available that doesn't have BT?

**Ordering**
[This article](https://github.com/rbaron/b-parasite/wiki/How-to-order:-PCB-fabrication-and-SMT-assembly) is probably a great reminder for the main developer, and enough for the experienced person, but it leaves most people with lots of questions. Let's run through my questions while trying to use JLCPCB.
**Q:** Which gerber files do you upload? **A:** All of them. Zip the entire folder as mentioned in step 1 and upload it.
**Q:** Are PCB settings like the amount of layers, PCB thickness etc. all set correctly or is the default fine?
**Q:** Same question as above, but for assembly options.
**Q:** JCBPCB offers a "conformal coating" option. Would it ever be a good idea to use this, or should we just use something like Plastik 70?
**Q:** I'm ordering 50 units, which results in over 300 bucks worth of E73 modules and over 70 bucks of DFN T&H sensors. Are those prices acceptable or should I source parts elsewhere?
**Q:** A part is not available at JLCPCB, how do I chose a replacement? (In my specific case it's the MMBT3906)

_(Addition on 2023/10/22)_
**Q:** Can sensors safely be omitted? I notice that the light sensor and T&H sensor both have a relatively high parts price (€0,10 and €1,50 respectively, plus €3 for each sensor type since they're non-default components), while both are only nice to have. The light sensor is even useless when using a case, which also severely limits the usefulness of the T&H sensor.
**Q:** Same question about the 2 buttons. I see one button is a reset button, but I assume taking the battery out will have the same effect?

I'd love for somebody to make a video about this device, just so everything's clear, I don't understand how this is one of the few DIY solutions that hasn't gotten any attention yet.

Timmiej93, 2023-10-23:
Just noticed that the discussion section is actually available on this repo, which I didn't notice before. Since this isn't an issue but a question/discussion, I moved it over there: https://github.com/rbaron/b-parasite/discussions/164.

Closed 2023-10-23.

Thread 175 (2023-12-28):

Bogus illuminance and moisture readings

drspangle, 2023-12-28:
Hey all, been a while. I recently came back to working on this project and decided to bring up one of my v1.2.0 b-parasites. Everything looks good, I've flashed it with the `ble` firmware sample using `bparasite_nrf52840@1.2.0` and it was detected immediately by Home Assistant. Great! I am getting good humidity and temperature readings, and the voltage readings seem fine as well. All three values look nominal when powered by coin cell or the debugger using pogo pins.

However, the illuminance values are stuck at 0 lx and the moisture values are stuck at 100%. It looks like all the components on the board are in good shape and I'm testing on my bench, so there's no grime or corrosion to speak of which would affect this. I expected the moisture readings to be 0% and the illuminance values do not vary regardless of lighting conditions.

I'm at a bit of a loss here. Maybe there's a calibration routine I've missed on, and maybe some simple probing on the board will give me some hints as to what's wrong? Any suggestions?

Edit: Never mind the illuminance readings, they're bogus because the component appears to have been installed backwards. I'm really just trying to diagnose the wonky moisture readings now.

drspangle, 2023-12-28:
I've managed to get my debugger working and am reading output from the `soil_read_loop` firmware sample, here's what it looks like for a few seconds' worth of output from having the sensor suspended in open air, powered by the debugger's 3v3:

```
[00:03:54.424,407] <inf> main: 3.29;0
[00:03:54.924,560] <inf> main: 3.30;0
[00:03:55.424,713] <inf> main: 3.30;4294967295
[00:03:55.924,835] <inf> main: 3.30;4294967295
[00:03:56.424,987] <inf> main: 3.30;4294967295
[00:03:56.925,140] <inf> main: 3.30;0
[00:03:57.425,262] <inf> main: 3.29;4294967295
[00:03:57.925,415] <inf> main: 3.30;4294967295
[00:03:58.425,567] <inf> main: 3.30;0
[00:03:58.925,689] <inf> main: 3.29;4294967295
[00:03:59.425,842] <inf> main: 3.30;4294967295
[00:03:59.925,994] <inf> main: 3.30;4294967294
[00:04:00.426,116] <inf> main: 3.30;0
[00:04:00.926,269] <inf> main: 3.31;4294967294
[00:04:01.426,422] <inf> main: 3.30;0
[00:04:01.926,544] <inf> main: 3.30;4294967295
[00:04:02.426,696] <inf> main: 3.30;0
[00:04:02.926,849] <inf> main: 3.30;0
[00:04:03.426,971] <inf> main: 3.30;0
[00:04:03.927,124] <inf> main: 3.31;4294967295
[00:04:04.427,276] <inf> main: 3.30;0
[00:04:04.927,398] <inf> main: 3.23;4294967295
[00:04:05.427,551] <inf> main: 3.25;4294967294
[00:04:05.927,703] <inf> main: 3.26;1
[00:04:06.427,825] <inf> main: 3.22;0
[00:04:06.927,978] <inf> main: 3.23;1
[00:04:07.428,131] <inf> main: 3.25;4294967294
[00:04:07.928,253] <inf> main: 3.23;4294967295
```

This seems pretty bogus to me. The "battery" readings from the 3v3 seem nominal, but the soil probe values seem to be totally garbage. I'm not sure what to do with this. Does this mean I've got a bad board (since the sensor is ostensibly the board itself)?

rbaron, 2023-12-28:
Hey @drspangle,

I would try, sorted by likelihood, difficulty:
1. Double check the module you have and the module you compiled for. The 1.2.0 hardware has a fast discharge circuit whose pins are different between modules. That could explain the error, since the capacitive pads never discharge
2. Look for shorts/cold solder joints, specially between adjacent module pads. I would pay special attention to pins 2 & 3, as they are related to the moisture sensor in the 1.2.0 version (`FAST_DISCH_EN` and `SENS_OUT` -- these are the second and third physical pads on the `nRF52840` module):

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

A few follow up questions:
1. Did you assembly this board yourself?
2. Do other boards from the same batch work with the same code?
3. What module are you using?
4. Any coating?

Please feel free to upload a photo of the board. Maybe we can spot something wrong with the components.

drspangle, 2023-12-28:
Thanks for the reply @rbaron.

>     Did you assembly this board yourself?
>     What module are you using?

No, I used JLCPCB and installed only the processor module. Here is a picture of the module, I can't seem to identify what the actual chipset is and I am hoping you might be able to identify it before I can.

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

>     Do other boards from the same batch work with the same code?

I have not attempted to bring up any other boards from this particular batch, so I can't use this to rule out anything sadly.

>     Any coating?

Not yet. I wanted to test a couple from this batch before I began coating them using your tried and tested method.

drspangle, 2023-12-28:
@rbaron I think I may have fixed a cold solder joint on pin 3 as it now has good continuity with R6. I also seem to have good continuity between pin 2 and R3. I also checked pin 15 and it has good connectivity with R4. That said, I'm still getting confusing readings from soil_read_loop (though they aren't zero constantly):
```
*** Booting Zephyr OS build zephyr-v3.5.0-3496-g87d056bd31b1 ***
[00:00:00.347,015] <dbg> pwm_nrfx: pwm_nrfx_set_cycles: channel 0, pulse 16, period 32, prescaler: 0.
[00:00:00.347,015] <inf> main: input_voltage;soil_adc_output
[00:00:00.847,167] <inf> main: 3.30;2
[00:00:01.347,320] <inf> main: 3.30;2
[00:00:01.847,442] <inf> main: 3.31;2
[00:00:02.347,595] <inf> main: 3.31;1
[00:00:02.847,747] <inf> main: 3.30;2
[00:00:03.347,869] <inf> main: 3.30;3
[00:00:03.848,022] <inf> main: 3.30;1
[00:00:04.348,175] <inf> main: 3.31;1
```

When I run the modified version as above, `soil_val_mv / 1000.0` is still always zero. There doesn't seem to be any variance when I squeeze the bottom of the PCB where the sensor is (in either the original soil_read_loop or the modified version). Am I misinterpreting something or missing something obvious?

rbaron, 2023-12-28:
Nice! I'm glad to hear you got it working. I will close the issue.

For coating and calibration, I've only ever used acrylic spray coating, and from my manual tests the coating layer is so thin that I saw little change in the capacitance measurement with and without coating, so I didn't bother maintaining two sets of calibration coefficients.

If you want to explore this further, I would compare the `soil_read_loop` readings from an uncoated board and a coated board with your preferred method. If they differ too much, you'll ideally have to calibrate it. I wrote [this](https://github.com/rbaron/b-parasite/issues/79#issuecomment-1637418626) and [this](https://github.com/rbaron/b-parasite/issues/79#issuecomment-1650278703) comments outlining how I did it.

It's up to personal preference, but depending on how much they differ (e.g.: up to 10-20%), I would not bother recalibrating it. Some other effects, like potential drift (#2) and positioning (#104) probably cause more variance in readings than fine tuning by calibration can resolve in my experience.

Closed 2023-12-28.

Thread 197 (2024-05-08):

Can not connect to the board. Target voltage too low?

Exeu, 2024-05-08:
Hi,

is there any more detailed guide in how to get the firmware on the borad properly?
I never used J-Link before and Just got an original JLInk Edu. For me it is fully unclear how i need to set this now up.

If i call JLinkExe and do the following:

`SEGGER J-Link Commander V7.96g (Compiled May  8 2024 15:00:40)
DLL version V7.96g, compiled May  8 2024 15:00:19

Connecting to J-Link via USB...O.K.
Firmware: J-Link ARM V8 compiled Nov 28 2014 13:44:46
Hardware version: V8.00
J-Link uptime (since boot): N/A (Not supported by this model)
S/N: 268006668
License(s): FlashBP, GDB
OEM: SEGGER-EDU
VTref=0.530V

Type "connect" to establish a target connection, '?' for help
J-Link>connect
Please specify device / core. <Default>: NRF52
Type '?' for selection dialog
Device>NRF52833_XXAA
Please specify target interface:
  J) JTAG (Default)
  S) SWD
  T) cJTAG
TIF>S
Specify target interface speed [kHz]. <Default>: 4000 kHz
Speed>
Device "NRF52833_XXAA" selected.

Connecting to target via SWD
Target voltage too low. Please check https://wiki.segger.com/J-Link_cannot_connect_to_the_CPU#Target_connection.
Error occurred: Could not connect to the target device.
For troubleshooting steps visit: https://wiki.segger.com/J-Link_Troubleshooting`

I enabled power with "Power ON" -> Removed the battery from my parasite board and connected the jlink to the proper pins.

I am a bit clueless what i need to do now

Exeu, 2024-05-08:
Ok i at least solved the problem with too low volage. I now connected VCC Pin to VTRef on Jlink... then it was at least working to connect.

But i now get a different issue:

`[error] [  JLink] - Failed to initialize CPU module in firmware because probe is low on memory (heap).
[error] [ Client] - Encountered error -11: Command read_device_info executed for 720 milliseconds with result -11
[error] [ Worker] - Could not connect to CPU core. This may indicate that AP protection is enabled.
Emulator does not have enough memory to perform the requested operation.
[error] [ Client] - Encountered error -104: Command read_memory_descriptors executed for 17 milliseconds with result -104
Failed to read device memories.
[error] [  nRF52] - Device memory generation failed.
[error] [ Worker] - JLinkARM.dll ReadMemU32 detected a read error 1.
 This typically indicates the read was blocked by a memory protection mechanism.
ERROR: nrfjprog failed for an unknown reason. Run the same command again with
ERROR: argument --log, contact Nordic Semiconductor and provide the generated
ERROR: log.log file to them.`

Closed 2024-05-08.

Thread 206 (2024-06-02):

Battery and soil sensor invalid readings (0mV)

seime, 2024-06-02:
Hi,

thank you for your great project!

I ordered a handful of these `v2.0.0` boards pre-soldered from JLCPCB (all components except the battery clip), and I've flashed them with the BLE example. However, the readings from the battery and soil sensor is always 0mV.

Here is an excerpt from the log:

```
00:03:13.918,640] <dbg> adc: get_soil_moisture_percent: Read soil moisture 2: 960.00 | Raw 4294967294 | Batt: 0.00 | Dry: 334.00 | Wet: 299.00
[00:03:13.918,701] <dbg> adc: get_soil_moisture_percent: Read soil moisture 2: 960.00 | Raw 4294967294 | Batt: 0.00 | Dry: 334.00 | Wet: 299.00
[00:03:13.928,863] <dbg> adc: prst_adc_photo_read: Read phototransistor: 142 lx | 0.02 V
[00:03:13.951,904] <dbg> shtc3: prst_shtc3_read: Read temp: 28.897552 oC (28)
[00:03:13.951,934] <dbg> shtc3: prst_shtc3_read: Read humi: 39 %
[00:03:13.951,965] <dbg> sensors: prst_sensors_read_all: Batt: 0 mV (0.00%)
[00:03:13.951,965] <dbg> sensors: prst_sensors_read_all: Soil: 100 % (0 mV)
[00:03:13.951,995] <dbg> sensors: prst_sensors_read_all: Photo: 142 lx (0 mV)
[00:03:13.951,995] <dbg> sensors: prst_sensors_read_all: Temp: 28.897552 oC
[00:03:13.952,026] <dbg> sensors: prst_sensors_read_all: Humi: 39 %
[00:03:13.952,056] <dbg> sensors: prst_sensors_read_all: --------------------------------------------------
[00:03:16.983,489] <dbg> adc: get_soil_moisture_percent: Read soil moisture 2: 965.71 | Raw 4294967292 | Batt: 0.00 | Dry: 334.00 | Wet: 299.00
[00:03:16.983,551] <dbg> adc: get_soil_moisture_percent: Read soil moisture 2: 965.71 | Raw 4294967292 | Batt: 0.00 | Dry: 334.00 | Wet: 299.00
[00:03:16.993,713] <dbg> adc: prst_adc_photo_read: Read phototransistor: 0 lx | 0.00 V
[00:03:17.016,754] <dbg> shtc3: prst_shtc3_read: Read temp: 28.878860 oC (28)
[00:03:17.016,784] <dbg> shtc3: prst_shtc3_read: Read humi: 39 %
[00:03:17.016,815] <dbg> sensors: prst_sensors_read_all: Batt: 0 mV (0.00%)
[00:03:17.016,815] <dbg> sensors: prst_sensors_read_all: Soil: 100 % (0 mV)
[00:03:17.016,845] <dbg> sensors: prst_sensors_read_all: Photo: 0 lx (0 mV)
[00:03:17.016,845] <dbg> sensors: prst_sensors_read_all: Temp: 28.878860 oC
[00:03:17.016,876] <dbg> sensors: prst_sensors_read_all: Humi: 39 %
[00:03:17.016,906] <dbg> sensors: prst_sensors_read_all: --------------------------------------------------
```

Debug steps taken so far:

- Tried 3 different boards, all with identical results
- Tried with and without the CR2032 battery installed (3v from JLink disconnected)
- Ensured there is connectivity form pin 3 (SENS_OUT) to R6

Reading of battery seen from the debugger:

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

Any suggestions on how to proceed debugging?

Thanks again for this cool project!

drspangle, 2024-06-02:
I would triple-check the soldering from the ESP to the main board. I had a similar situation with a few of mine and after resoldering (one of them took a few tries) it was successful.

seime, 2024-06-02:
Thanks, I did a triple check on one of the boards. All pads _apparently_ connected (by measuring). Tried resoldering one side, but as I dont have suitable equipment for SMD I'm afraid I'll do more damage than good.

The reason I ordered pre-assembled on JLCPCB was to ensure proper soldering. My expectations were that all pads are actually soldered, but as I do not have any prior experience ordering custom PCBs I might have expected too much?

rbaron, 2024-06-02:
Hi @seime, tks for the kind words. Glad to hear you managed to order and flash the boards.

From the logs, it looks like all ADC functionality is acting weird -- battery, soil moisture and illuminance are all reading 0 V. The battery measurement is internal to the nRF52 chip, so I would first rule out other issues than soldering -- although this issue has happened to me as well. If the module is powered up and running (which it is), I would expect it to read a valid batt voltage.

We support both `nRF52840` and the `nRF52833` modules. I would check that you built the sample for the correct variant and version (e.g.: `bparasite_nrf52840` & 2.0.0). This would be my first guess. I would also double check the module that JLCPCB soldered on the board (e.g.: `E73-2G4M08S1C` `E73-2G4M08S1E`). Just to be sure: if you're providing external power, do not use a battery and vice-versa.

Let us know how it goes, and I can try thinking of other possible issues.

seime, 2024-06-02:
Thanks for your prompt reply @rbaron .

I'm using the nRF52840 in the E73-2G4M08S1C module.

I tried to change the overlay file to the bparasite specific one, and then at least battery voltage came alive:

This is the config I tried:

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

```west build --build-dir /opt/openhab/b-parasite/code/nrf-connect/samples/ble/build /opt/openhab/b-parasite/code/nrf-connect/samples/ble --pristine --board bparasite_nrf52840@2.0.0 --no-sysbuild -- -DNCS_TOOLCHAIN_VERSION=NONE -DBOARD_ROOT=/opt/openhab/b-parasite/code/nrf-connect/prstlib -DCACHED_CONF_FILE=/opt/openhab/b-parasite/code/nrf-connect/samples/ble/prj.conf -DDTC_OVERLAY_FILE=/opt/openhab/b-parasite/code/nrf-connect/prstlib/boards/arm/bparasite_nrf52840/bparasite_nrf52840_2_0_0.overlay```

Output is now

```
[00:08:20.435,577] <dbg> sensors: prst_sensors_read_all: --------------------------------------------------
[00:08:23.467,010] <dbg> adc: get_soil_moisture_percent: Read soil moisture 2: -4.06 | Raw 546 | Batt: 3.30 | Dry: 530.42 | Wet: 146.70
[00:08:23.467,071] <dbg> adc: get_soil_moisture_percent: Read soil moisture 2: -4.06 | Raw 546 | Batt: 3.30 | Dry: 530.42 | Wet: 146.70
[00:08:23.477,233] <dbg> adc: prst_adc_photo_read: Read phototransistor: 8498 lx | 1.43 V
[00:08:23.500,244] <dbg> shtc3: prst_shtc3_read: Read temp: 29.129868 oC (29)
[00:08:23.500,274] <dbg> shtc3: prst_shtc3_read: Read humi: 43 %
[00:08:23.500,305] <dbg> sensors: prst_sensors_read_all: Batt: 3304 mV (100.00%)
[00:08:23.500,305] <dbg> sensors: prst_sensors_read_all: Soil: 0 % (0 mV)
[00:08:23.500,335] <dbg> sensors: prst_sensors_read_all: Photo: 8498 lx (0 mV)
[00:08:23.500,335] <dbg> sensors: prst_sensors_read_all: Temp: 29.129868 oC
```

Ie the battery voltage is now also working. The light sensor was working before as well - that is the lux value is updating but the voltage is always reported at 0... Soil sensor still reading 0mV.

Newbie question to nrf programming: The device overlays, is it supposed to be just 1 in our case - or more?

rbaron, 2024-06-02:
It looks like it's a good step in the right direction. I have a feeling it could be actually working now, but something is off in the logging of float values (compare the 100% soil moisture before to 0% now; and also the 1.43 V for the illuminance vs. 0.02 V before). You can quickly check by resetting the board while squeezing the sensor in your hand -- the soil moisture should say 50%+.

The float print issue could be related to `CONFIG_NEWLIB_LIBC` and [`CONFIG_NEWLIB_LIBC_FLOAT_PRINTF`](https://developer.nordicsemi.com/nRF_Connect_SDK/doc/latest/kconfig/index.html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), but since [these should be enabled in the ble sample](https://github.com/rbaron/b-parasite/blob/main/code/nrf-connect/samples/ble/prj.conf#L18), I think there's something else going on with the build that is preventing these configs from working.

In VSCode, I've never had to manually specify the overlay file -- it should be automatically loaded by west from the `--board` switch. I.e.: `--board bparasite_nrf52840@2.0.0` should auto load `prstlib/boards/arm/bparasite_nrf52840/bparasite_nrf52840_2_0_0.overlay`. Are you opening VSCode from the `ble.code-workspace` file?

seime, 2024-06-03:
Good morning,

Apparently I have done something wrong when I opened the project and built the firmware. After reopening the workspace file it works "better".

This is what I get when I press a finger on the board;

`          ``
[00:00:13.128,875] <dbg> sensors: prst_sensors_read_all: --------------------------------------------------
[00:00:16.160,278] <dbg> adc: get_soil_moisture_percent: Read soil moisture 2: 42.59 | Raw 367 | Batt: 3.30 | Dry: 530.39 | Wet: 146.73
[00:00:16.160,339] <dbg> adc: get_soil_moisture_percent: Read soil moisture 2: 42.59 | Raw 367 | Batt: 3.30 | Dry: 530.39 | Wet: 146.73
[00:00:16.160,400] <dbg> adc: get_soil_moisture_percent: Read soil moisture 2: 42.59 | Raw 367 | Batt: 3.30 | Dry: 530.39 | Wet: 146.73
[00:00:16.160,430] <dbg> adc: get_soil_moisture_percent: Read soil moisture 2: 42.59 | Raw 367 | Batt: 3.30 | Dry: 530.39 | Wet: 146.73
[00:00:16.170,593] <dbg> adc: prst_adc_photo_read: Read phototransistor: 82 lx | 0.01 V
[00:00:16.193,634] <dbg> shtc3: prst_shtc3_read: Read temp: 26.817398 oC (26)
[00:00:16.193,664] <dbg> shtc3: prst_shtc3_read: Read humi: 37 %
[00:00:16.193,695] <dbg> sensors: prst_sensors_read_all: Batt: 3301 mV (100.00%)
[00:00:16.193,695] <dbg> sensors: prst_sensors_read_all: Soil: 43 % (0 mV)
[00:00:16.193,725] <dbg> sensors: prst_sensors_read_all: Photo: 82 lx (0 mV)
[00:00:16.193,756] <dbg> sensors: prst_sensors_read_all: Temp: 26.817398 oC
[00:00:16.193,756] <dbg> sensors: prst_sensors_read_all: Humi: 37 %
[00:00:16.193,786] <dbg> sensors: prst_sensors_read_all: --------------------------------------------------
```

The debug log always logs `0 mV` on the `Soil` and `Photo` sensor, even if the percentage and lx values change

Edit: Photo logging is using soil adc reading; fixed here: https://github.com/rbaron/b-parasite/pull/207

Still the soil reading seems to not get converted to millivolts. I can see the raw value changed based on finger pressure:

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

Still something wrong with the overlay?

rbaron, 2024-06-04:
Hey @seime, thanks for the PR! Nice catch.

For the `0 mV` in the soil moisture reading, the situation is a bit more involved. We sample the ADC peripheral at the soil moisture sensor pin and get back a "raw" value. In our case, this is a 10-bit value from 0-1024.

Then we call [adc_raw_to_millivolts_dt](https://docs.zephyrproject.org/latest/hardware/peripherals/adc.html#c.adc_raw_to_millivolts_dt) that converts the raw value into a millivolt value, taking into account how the ADC channel is configured.

For the battery and the phototransistor, this works fine, because they use the 0.6 internal reference in their channels ([example](https://github.com/rbaron/b-parasite/blob/ccdbaaf142c0d5e12d5ab070e809df4f5cd843d6/code/nrf-connect/prstlib/boards/arm/bparasite_nrf52840/bparasite_nrf52840.dts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)). For the soil moisture sampling, I configured it to use the `VDD` as a reference, to try and make the readings more or less agnostic to the current battery level ([here](https://github.com/rbaron/b-parasite/blob/ccdbaaf142c0d5e12d5ab070e809df4f5cd843d6/code/nrf-connect/prstlib/boards/arm/bparasite_nrf52840/bparasite_nrf52840.dts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)).

But it looks like then `adc_raw_to_millivolts_dt` doesn't work well and returns 0 every time. I did a quick test by changing the ref to `ADC_REF_INTERNAL` and it does work. Maybe there's a workaround, but either way it doesn't impact us that much, other than that logging line -- the soil moisture estimation is done over the raw values anyway.

So for now I will suggest that we remove the `millivolts` from the line that logs soil moisture in `sensors.c`. Let me know if you want to do that in your PR as well, otherwise I will send another one.

Tks!

seime, 2024-06-04:
Thanks @rbaron, I've updated the PR removing the soil voltage reading.

Thanks again for your awesome support in resolving my issue!

rbaron, 2024-06-04:
Tks!

Closed 2024-06-04.

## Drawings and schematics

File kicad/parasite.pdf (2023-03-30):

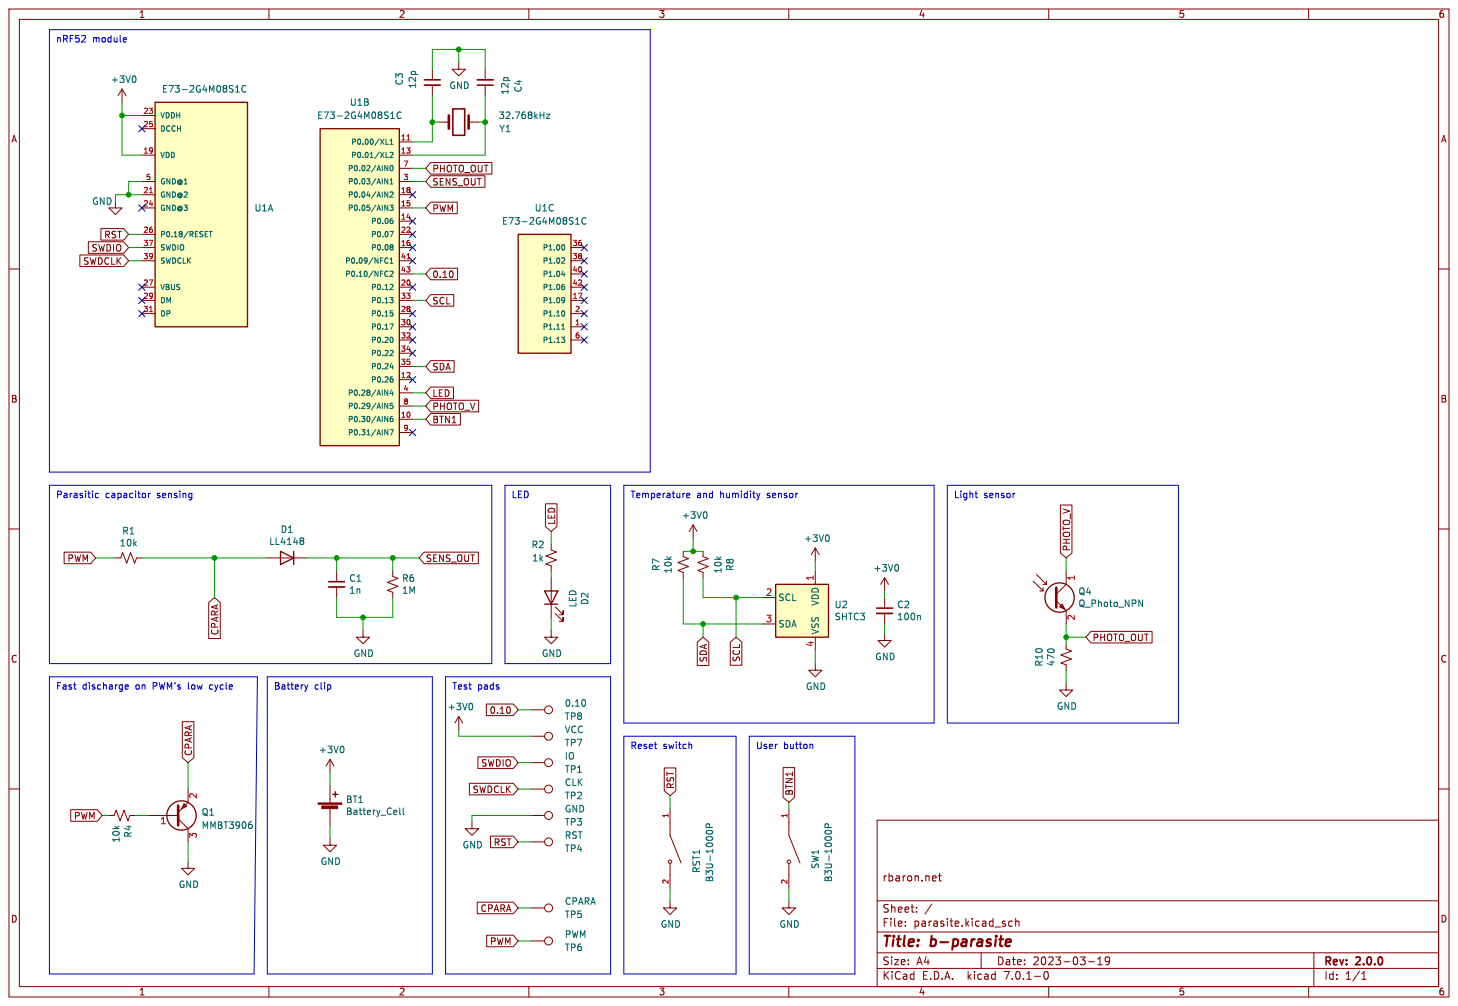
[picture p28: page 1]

Light sensor Battery clip

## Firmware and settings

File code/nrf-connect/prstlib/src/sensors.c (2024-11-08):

#include "prstlib/sensors.h"

#include <zephyr/logging/log.h>

#include "prstlib/adc.h"
#include "prstlib/led.h"
#include "prstlib/macros.h"

LOG_MODULE_REGISTER(sensors, CONFIG_PRSTLIB_LOG_LEVEL);

int prst_sensors_read_all(prst_sensors_t *sensors) {
  RET_IF_ERR(prst_adc_batt_read(&sensors->batt));
  RET_IF_ERR(prst_adc_soil_read(sensors->batt.adc_read.voltage, &sensors->soil));
  RET_IF_ERR(prst_adc_photo_read(sensors->batt.adc_read.voltage, &sensors->photo));
  RET_IF_ERR(prst_shtc3_read(&sensors->shtc3))

  LOG_DBG("Batt: %d mV (%.2f%%)", sensors->batt.adc_read.millivolts,
          DOUBLE_PROMO_OK(100 * sensors->batt.percentage));
  LOG_DBG("Soil: %.0f %%", DOUBLE_PROMO_OK(100 * sensors->soil.percentage));
  LOG_DBG("Photo: %u lx (%d mV)", sensors->photo.brightness,
          sensors->photo.adc_read.millivolts);
  LOG_DBG("Temp: %f oC", DOUBLE_PROMO_OK(sensors->shtc3.temp_c));
  LOG_DBG("Humi: %.0f %%", DOUBLE_PROMO_OK(100 * sensors->shtc3.rel_humi));
  LOG_DBG("--------------------------------------------------");

  return 0;
}

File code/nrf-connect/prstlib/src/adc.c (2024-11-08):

#include "prstlib/adc.h"

#include <math.h>
#include <zephyr/devicetree.h>
#include <zephyr/drivers/adc.h>
#include <zephyr/drivers/gpio.h>
#include <zephyr/drivers/pwm.h>
#include <zephyr/kernel.h>
#include <zephyr/logging/log.h>

#include "prstlib/macros.h"

LOG_MODULE_REGISTER(adc, CONFIG_PRSTLIB_LOG_LEVEL);

// PWM spec for square wave. Input to the soil sensing circuit.
static const struct pwm_dt_spec soil_pwm_dt =
    PWM_DT_SPEC_GET(DT_NODELABEL(soil_pwm));
static const uint32_t pulse = DT_PROP(DT_NODELABEL(soil_pwm), pulse);

// Calibration coefficients for the soil sensing circuit.
static const int dry_coeffs[3] = DT_PROP(DT_NODELABEL(soil_calibration_coeffs), dry);
static const int wet_coeffs[3] = DT_PROP(DT_NODELABEL(soil_calibration_coeffs), wet);

struct gpio_dt_spec fast_disch_dt =
    GPIO_DT_SPEC_GET(DT_NODELABEL(fast_disch), gpios);

// Shared buffer and adc_sequennce.
static int16_t buf;
static struct adc_sequence sequence = {
    .buffer = &buf,
    .buffer_size = sizeof(buf),
};

static const struct adc_dt_spec adc_soil_spec =
    ADC_DT_SPEC_GET_BY_IDX(DT_PATH(zephyr_user), 0);

static const struct adc_dt_spec adc_batt_spec =
    ADC_DT_SPEC_GET_BY_IDX(DT_PATH(zephyr_user), 1);

#if DT_NODE_EXISTS(DT_NODELABEL(photo_transistor))

static const struct adc_dt_spec adc_photo_transistor_spec =
    ADC_DT_SPEC_GET(DT_NODELABEL(photo_transistor));
struct gpio_dt_spec photo_transistor_enable_dt =
    GPIO_DT_SPEC_GET(DT_NODELABEL(photo_transistor_enable), gpios);

#elif DT_NODE_EXISTS(DT_NODELABEL(ldr))

static const struct adc_dt_spec adc_ldr_spec =
    ADC_DT_SPEC_GET(DT_NODELABEL(ldr));
struct gpio_dt_spec ldr_enable_dt =
    GPIO_DT_SPEC_GET(DT_NODELABEL(ldr_enable), gpios);

#endif

typedef struct {
  // High (h) and low (p) voltage (v) and % (p) points.
  float vh, vl, ph, pl;
} batt_disch_linear_section_t;

static void set_battery_percent(const prst_adc_read_t* read, prst_batt_t* out) {
  // Must be sorted by .vh.
  static const batt_disch_linear_section_t sections[] = {
      {.vh = 3.00f, .vl = 2.90f, .ph = 1.00f, .pl = 0.42f},
      {.vh = 2.90f, .vl = 2.74f, .ph = 0.42f, .pl = 0.18f},
      {.vh = 2.74f, .vl = 2.44f, .ph = 0.18f, .pl = 0.06f},
      {.vh = 2.44f, .vl = 2.01f, .ph = 0.06f, .pl = 0.00f},
  };

  const float v = read->voltage;

  if (v > sections[0].vh) {
    out->percentage = 1.0f;
    return;
  }
  for (int i = 0; i < ARRAY_SIZE(sections); i++) {
    const batt_disch_linear_section_t* s = &sections[i];
    if (v > s->vl) {
      out->percentage = s->pl + (v - s->vl) * ((s->ph - s->pl) / (s->vh - s->vl));
      return;
    }
  }
  out->percentage = 0.0f;
  return;
}

static inline float eval_poly(const int coeffs[3], float x) {
  // The coefficients are specified times 1000, as a workaround the lack of support for floating
  // points in devicetree bindings.
  return (coeffs[0] + coeffs[1] * x + coeffs[2] * x * x) / 1000.0f;
}

static inline float get_soil_moisture_percent(float battery_voltage,
                                              int16_t raw_adc_output) {
  const float x = battery_voltage;
  const float dry = eval_poly(dry_coeffs, x);
  const float wet = eval_poly(wet_coeffs, x);
  const float percent = (raw_adc_output - dry) / (wet - dry);
  LOG_DBG("Read soil moisture 2: %.2f | Raw %u | Batt: %.2f | Dry: %.2f | Wet: %.2f",
          DOUBLE_PROMO_OK(100 * percent),
          raw_adc_output, DOUBLE_PROMO_OK(x), DOUBLE_PROMO_OK(dry), DOUBLE_PROMO_OK(wet));
  return percent;
}

static int read_adc_spec(const struct adc_dt_spec* spec, prst_adc_read_t* out) {
  RET_IF_ERR(adc_sequence_init_dt(spec, &sequence));

  RET_IF_ERR(adc_read(spec->dev, &sequence));

  int32_t val_mv = buf;
  RET_IF_ERR(adc_raw_to_millivolts_dt(spec, &val_mv));
  val_mv = MAX(0, val_mv);

  out->raw = buf;
  out->millivolts = val_mv;
  out->voltage = val_mv / 1000.0f;
  return 0;
}

int prst_adc_init() {
  RET_IF_ERR(adc_channel_setup_dt(&adc_soil_spec));
  RET_IF_ERR(adc_channel_setup_dt(&adc_batt_spec));

  RET_IF_ERR(!device_is_ready(fast_disch_dt.port));
  RET_IF_ERR(gpio_pin_configure_dt(&fast_disch_dt, GPIO_OUTPUT));

#if DT_NODE_EXISTS(DT_NODELABEL(photo_transistor))
  RET_IF_ERR(adc_channel_setup_dt(&adc_photo_transistor_spec));
  RET_IF_ERR(!device_is_ready(photo_transistor_enable_dt.port));
  RET_IF_ERR(gpio_pin_configure_dt(&photo_transistor_enable_dt, GPIO_OUTPUT));
#elif DT_NODE_EXISTS(DT_NODELABEL(ldr))
  RET_IF_ERR(adc_channel_setup_dt(&adc_ldr_spec));
  RET_IF_ERR(!device_is_ready(ldr_enable_dt.port));
  RET_IF_ERR(gpio_pin_configure_dt(&ldr_enable_dt, GPIO_OUTPUT));
#endif

  for (size_t idx = 0; idx < ARRAY_SIZE(dry_coeffs); idx++) {
    LOG_DBG("Dry coeff %d: %d\n", idx, dry_coeffs[idx]);
  }
  for (size_t idx = 0; idx < ARRAY_SIZE(wet_coeffs); idx++) {
    LOG_DBG("Wet coeff %d: %d\n", idx, wet_coeffs[idx]);
  }
  return 0;
}

int prst_adc_batt_read(prst_batt_t* out) {
  RET_IF_ERR(read_adc_spec(&adc_batt_spec, &out->adc_read));
  set_battery_percent(&out->adc_read, out);
  return 0;
}

int prst_adc_soil_read(float battery_voltage, prst_adc_soil_moisture_t* out) {
  // Enable fast discharge circuit.
  RET_IF_ERR(gpio_pin_set_dt(&fast_disch_dt, 1));
  // Start PWM.
  RET_IF_ERR(pwm_set_dt(&soil_pwm_dt, soil_pwm_dt.period, pulse));
  k_msleep(30);
  RET_IF_ERR(read_adc_spec(&adc_soil_spec, &out->adc_read));
  // Stop PWM.
  RET_IF_ERR(pwm_set_dt(&soil_pwm_dt, 0, 0));
  // Turn off fast discharge circuit.
  RET_IF_ERR(gpio_pin_set_dt(&fast_disch_dt, 0));
  out->percentage =
      MAX(0.0f, MIN(1.0f, get_soil_moisture_percent(battery_voltage, buf)));
  return 0;
}

int prst_adc_photo_read(float battery_voltage, prst_adc_photo_sensor_t* out) {
#if DT_NODE_EXISTS(DT_NODELABEL(photo_transistor))
  RET_IF_ERR(gpio_pin_set_dt(&photo_transistor_enable_dt, 1));
  k_msleep(10);
  RET_IF_ERR(read_adc_spec(&adc_photo_transistor_spec, &out->adc_read));
  RET_IF_ERR(gpio_pin_set_dt(&photo_transistor_enable_dt, 0));
  const float phototransistor_resistor = DT_PROP(DT_NODELABEL(photo_transistor), output_ohms);
  // Assuming 10000 lux for the saturation test. Calibration with a proper light
  // meter would be better.
  const float lux_sun = 10000.0f;
  const float current_sun = 3.59e-3f;
  const float current = out->adc_read.voltage / phototransistor_resistor;
  out->brightness = MAX(0, MIN(lux_sun * current / current_sun, UINT16_MAX));
  LOG_DBG("Read phototransistor: %u lx | %.2f V", out->brightness, DOUBLE_PROMO_OK(out->adc_read.voltage));
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

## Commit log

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2021-02-10 Serial upload works.
    Currently uploading via the Arduino IDE and PlatformIO works. But it's not perfect yet:
    1. We're using a custom-compiled bootloader for the e73 board, which is nice;
    2. We're still using `board = adafruit_feather_nrf52832` in the `platformio.ini` file. Using our custom board `boards/e73-tbb.json` doesn't work yet. Uploading results in a `*** [upload] IndexError : list index out of range` error. Most likely has to be fixed in https://github.com/platformio/platform-nordicnrf52/blob/develop/builder/main.py.
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2021-02-19 Implement ADC correction for the soil sensor for a range of input voltages
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2021-02-20 Fixes rtc playground example
    [main.c]
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2021-02-23 Initial commit with parasite52832
    [parasite.csv, parasite.kicad_pcb, parasite.sch]
2021-02-23 Some minor adjustements on pcbnew
    [parasite-B_Cu.gbr, parasite-B_Mask.gbr, parasite-B_Paste.gbr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]
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2021-02-23 Adds sht30 temperature and humidity sensor
    [parasite-B_Cu.gbr, parasite-B_Mask.gbr, parasite-B_Paste.gbr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]
2021-02-24 Plotted gerbers for parasite52832
    [parasite-B_Cu.gbr, parasite-B_Mask.gbr, parasite-B_Paste.gbr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]
2021-03-11 Updates schematic - disconnects USB shield from GND
    [parasite-B_Cu.gbr, parasite-B_Mask.gbr, parasite-B_Paste.gbr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]
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2021-03-12 b-parasite v1.0.0
    [parasite-B_Cu.gbr, parasite-B_Mask.gbr, parasite-B_Paste.gbr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]
2021-03-12 Plotted v1.0.0
    [parasite-B_Cu.gbr, parasite-B_Mask.gbr, parasite-B_Paste.gbr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]
2021-03-13 Removes wrong + markings from the PCB silkscreen
    [parasite-B_Cu.gbr, parasite-B_Mask.gbr, parasite-B_Paste.gbr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]
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2021-03-14 PWM start/stop in RTC callback.
    I initially tried calling prst_pwm_init() in main(), and just using start/stop in
    the callback, but that led to a weird behavior in the PWM output. It was set to
    high after the end of the callback.
    Callnig uninit/re-calling init() inside the RTC callback fixed, but more investigation
    is required.
    [main.c]
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2021-03-15 A hacky fix for PWM + TWI
    [main.c, shtc3.c]
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2021-03-31 Sets transmitting power to +8dB
    [dry.csv, wet.csv]
2021-03-31 Corrects the raw ADC soil mesasure given the current input voltage
    [adc.c, main.c]
2021-04-08 Updates Q1, Q2, Q3 orientation in kicad/parasite-top-pos.csv
    [parasite-B_Cu.gbr, parasite-B_Mask.gbr, parasite-B_Paste.gbr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]
2021-04-10 Adds stl and step files for a 3d printable case
    [Bottom.stl, Case.step, Top.stl]
2021-04-26 Fixes possible overflow in the soil moisture BLE encoding
    [adc.c]
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2021-05-31 Adds the E73-2G4M08S1C module to the BOM and pick-and-place files
    Note: the pick-and-place of the E73 has not been tested, since the module is currently unavailable at LCSC.
    [parasite.csv, parasite.sch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]
2021-09-03 Fix pinout for fast discharge pin
2021-09-22 Add Photoresistor
    [parasite-B_Cu.gbr, parasite-B_Mask.gbr, parasite-B_Paste.gbr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]
2021-09-22 Supply V to photoresitor using nrf pin
    [parasite.csv, parasite.kicad_pcb, parasite.sch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]
2021-09-22 minor adjustments to silkscreen
    [parasite.kicad_pcb]
2021-09-22 Update GERBER
    [parasite-B_Cu.gbr, parasite-B_Mask.gbr, parasite-B_Paste.gbr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]
2021-09-22 simplify voltage divider
    [parasite-B_Cu.gbr, parasite-B_Mask.gbr, parasite-B_Paste.gbr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]
2021-09-22 First draft for Photoresistor
    the code now should setup and use the photoresistor and read it's value by the adc.
    the returned value is 0 just as a place holder until the correct values are measured.
    [adc.c, main.c]
2021-09-22 Calculate photoresistor and some other fixes (#3)
    prst_adc_photo_read() now calculates the photo resistor and return it as the lux level.
    Added debug logging and fixed some syntax errors.
    [adc.c, main.c]
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2021-09-22 Bumps revision to 1.1.0
    Merges both drill files into a single one.
    [parasite.kicad_pcb, parasite.sch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]
2021-09-22 Updates PHOTO_V pin to use pin P0.29 from both modules
    - Updated schematic
    - Updated pcb layout
    [parasite.kicad_pcb, parasite.sch]
2021-09-22 Plotted gerbers and schematic PDF
    [parasite-B_Cu.gbr, parasite-B_Mask.gbr, parasite-B_Paste.gbr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]
2021-09-22 Generates footprint position file & BOM
    [parasite.csv, parasite.sch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]
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2021-09-22 Adds LCSC part number to the R9 photoresistor
    [parasite.sch]
2021-09-30 Fix overflow in very dark or noisy situations
    [adc.c]
2021-10-09 First step in adding the phototransistor
    - Updates schematic
    - Updates the PCB layout
    - Generated BOM file
    [parasite.csv, parasite.kicad_pcb, parasite.sch]
2021-10-09 Plots fabrication files
    This also adds ~15mm to the length of the board. This extra clearance
    should help prevent shorts when watering plants.
    [parasite-B_Cu.gbr, parasite-B_Mask.gbr, parasite-B_Paste.gbr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]
2021-10-09 Fixes Q4 (phototransistor footprint)
    It was not marked as SMT, so the exported position file didn't include
    it.
    [parasite-B_Cu.gbr, parasite-B_Mask.gbr, parasite-B_Paste.gbr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]
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2021-10-09 Accidentally cleaned up too much
    [adc.c]
2021-10-09 Moves photoresistor all the way to the top & adds test pad
    [parasite-B_Cu.gbr, parasite-B_Mask.gbr, parasite-B_Paste.gbr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]
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2021-10-18 Removes C_para from BOM file
    The C_para is just a virtual capacitor, formed by the PCB traces, and
    should not have an entry in the BOM file.
    [parasite.csv]
2021-12-13 Fixed LCSC part number for resistor R10
    Fixes #23
    [parasite.csv, parasite.sch]
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2022-03-14 Implements BLE protocol v2
    The only change from v1 is how the temperature is encoded. In v2, two
    bytes at offset 4 and 5 represent a 16-bit signed int (in big-endian).
    It contains the temperature in degrees Celsius * 100.
    Fixes #29
    [main.c, shtc3.c]
2022-04-28 Added gas exchange holes, cutout for photosensor, pry slots
    [Case.step, Top.stl]
2022-04-28 Reorganized case files
    +STEP file now contains both case top versions
    +Restored original Top STL (without holes)
    +Added new Top-holes STL (has the holes for the photosensor and humidity sensor)
    [Case.step, Top-holes.stl, Top.stl]
2022-05-18 Moves KiCad project file to KiCad 6
    Moved the Q4 photodiode footprint dot (representing the collector) so
    it's more clearly visible. Hopefully it will help addressing the
    recurring confusion about Q4's orientation (#3, #42).
    [parasite.kicad_pcb]
2022-07-07 Fix a couple of spelling errors and whitespaces.
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2022-08-29 Fixes humidity factor & removes illumminance
    The reason for removing illuminance is to leave enough space for the
    full name AD element "prst". There may be options for also sending the
    illuminance (extended adv, scan response etc), with different power
    consumption/overhead/complexity tradeoffs. For now let's keep it simple.
2022-09-09 Update "Battery Life" section in README.md
    Fixes #48.
2022-09-29 replace R10 LCSC part with equivalent without extra fee
    [parasite.csv, parasite.sch]
2022-09-29 Open sources the rotisserie / spinning drying jig
    Fixes #63
    [case.stl, gear.stl, gear_cap.stl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]
2022-10-10 high airflow case design stl and 3mf files
    [b_parasite_case_high_airflow.3mf, b_parasite_case_high_airflow.stl]
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2022-11-06 Uses a single PNP BJT in the fast discharge circuit
    [parasite.csv, parasite.kicad_pcb, parasite.kicad_sch]
2022-11-08 Adds missing base.stl to experimental/rotisserie
    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
    [base.stl]
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2022-11-13 Better error handling in adc.c
    [adc.c, main.c]
2022-11-13 Some hacky macros for error handling
    [adc.c, main.c]
2022-11-14 Started adding a b-parasite board. Not working yet
2022-11-14 Revert "Uses a single PNP BJT in the fast discharge circuit"
    This reverts commit fb7dff8bfe918f582788ee82183afc4dbe65c534.
    Fixes #72
    [parasite.csv, parasite.kicad_pcb, parasite.kicad_sch]
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2022-11-22 Fixs PWM current consumption - SYSTEM ON sleep @ ~2.7uA
    [adc.c, button.c, main.c]
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2022-12-03 Fixes GitHub actions to use board revisions
    [main.c]
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2022-12-03 Fix BTHome v2 encoding - sort entries by Object IDs
    [encoding.c]
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2022-12-04 Fix illuminance encoding in ble, BTHome v2
    [encoding.c]
2022-12-04 Really fixing BTHome v2 illuminance encoding this time
    [encoding.c]
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2022-12-07 Custom Soil Moisture cluster works! :)
    This commits adds a Soil Moisture cluster according to the one that
    exists in https://github.com/Koenkk/zigbee-herdsman/blob/master/src/zcl/definition/cluster.ts#L2570.
    The cluster Id is 1032 (I didn't find it in the official specs).
    [main.c]
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2022-12-10 Implemented a pairing-reset detection strategy
    This is a "tricky" workaround due to the lack of physical buttons:
    We can distinguish between the two "power up" modes:
    - Power on: when the device receives power for the first time. Example:
    swapping batteries, prroviding external power. This _DOES NOT_ reset the
    pairing info.
    - Reset pin: when the device is manually reset (by shorting the RESET
    pin to GND), or when a new firmware is flashed. This _RESETS_ the
    pairing info.
    [main.c]
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2022-12-16 Fixing sensor logging millivolts.
    [sensors.c]
2022-12-16 Fixed bug in cluster list not connecting power cluster.
    [main.c]
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2022-12-21 Fix ADC config for nRF52833
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2022-12-27 [zb] Implement double-reset factory resetting method
    [main.c]
2023-01-12 Fix: Counter was missing
    [encoding.c]
2023-01-22 Update Zigbee example to work with SDK 2.2.0
    The new SDK requires 802.15.4 to be enabled in the board DTS file.
    Also disable IPv6 explicitly to avoid compile errors related to its
    network stack, since it is not used currently.
    Closes #94
2023-01-23 Update containers to use SDK 2.2.0
    The zigbee sample no longer compiles with SDK 2.1, so update the used
    docker image to 2.2.0.
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2023-02-02 Fix battery quantity/size reporting
    The API for reporting information requires a pointer to the data value,
    and cannot deal with a constant directly. The current quantity/size
    returned by the device are random values from memory.
    Instead move these values into the prst_batt_attrs_t struct and
    set their values in prst_zb_attrs_init.
    [main.c]
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2023-03-11 updated high airflow model
    modified the high airflow model to increase the print reliability
    [b-parasite-high-airflow.3mf, b-parasite-high-airflow.stl]
2023-03-19 Some initial hardware changes for the 2.0.0 revision
    - Simplified the fast discharge circuit to use a single PNP BJT instead
    of two NPN BJTs
    - Swapped nRF52 module's footprint for one with larger pads
    - Added a user button tied to P0.12 (same as Button 2 from [nrf52840_dk](https://infocenter.nordicsemi.com/index.jsp?topic=%2Fug_nrf52840_dk%2FUG%2Fdk%2Fhw_buttons_leds.html))
    - Added a reset switch
    These are only schematic changes - PCB layout is stale and needs to be
    recreated.
    [parasite.kicad_sch]
2023-03-19 New PWM testpoint and added LCSC part # for the E73 module
    [parasite.csv, parasite.kicad_sch]
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2023-03-19 Adds sketch of RC circuit in silkscreen
    [parasite.kicad_pcb]
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2023-03-19 Routed 0.10 to a new test pad
    [parasite.kicad_pcb, parasite.kicad_sch]
2023-03-19 Fix drawing
    [parasite.kicad_pcb]
2023-03-19 Plot PDF & generate BOM
    [parasite.csv, parasite.kicad_pcb, parasite.kicad_sch]
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2023-03-19 Fix stale silkscreen 1.2.0 -> 2.0.0
    [parasite-B_Cu.gbr, parasite-B_Mask.gbr, parasite-B_Paste.gbr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]
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2023-03-19 Store calibration polynomial in devicetree
    This will enable us to transparently use different calibration for
    different board revisions. The 2.0.0 revision changes the sensing
    circuitry and will need its own coeffs.
    In this commit, both models are run in parallel for debugging.
    [soil-calibration-coeffs.yaml]
2023-03-19 Fix devicetree-coeffs bug
    [soil-calibration-coeffs.yaml]
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2023-03-19 BIG YIKES - Fix wrong symbol/footprint for MMBT3906 (Q1)
    I previously used a basic 2N3906 and then changed its footprint to
    SOT-23. This led to the wrong pin assignment.
    This commit fixes it by using the correct symbol and footprint for it.
    Note that the PCB layout still needs fixing.
    [parasite.kicad_pcb, parasite.kicad_sch]
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2023-03-19 Fixes Q1 in PCB layout. I think
    [parasite.kicad_pcb]
2023-03-19 Updates SW1 location and pin
    Previous, SW1 was too close to RST, making it difficult to press one
    without pressing another. After changing its position, it was more
    convenient to route SW1 to pin 10 on U1 - That's P0.30/AIN6 both on
    nRF52840 (C) and nRF52833 (E) modules.
    [parasite.kicad_pcb, parasite.kicad_sch]
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2023-03-19 Update date on pcbnew
    [parasite.kicad_pcb]
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2023-03-29 Implements button handling
    - DTS bindings
    - Debouncing logic
    - New `input` for testing and interrupt power profiling
    [button.c, main.c]
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2023-05-10 Implement workaround for errata KRKNWK-12017
    Nordic has published an errata for the nRF Connect SDK for versions
    >1.8.0 where a Zigbee End Device can end up getting stuck if the
    parent device does not acknowledge the "Device Announcement packet".
    They have a suggested workaround to implement in the SDK, which has
    been adapted for the custom signal handler used here.
    This is an effort to solve issues where my parasites would occasionally
    drop off my network and require a reboot. After 24Hrs, I've not yet
    had a device disappear but it has taken >weeks before a device would
    fail. Unforunately it's hard to debug the board as the chips are in a
    low power state when this occurs.
    [main.c]
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2023-06-02 Fixed api of restart watchdog.
    [main.c]
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2023-06-15 Introduce CONFIG_BOARD_REVISION_CODE
    Beside having a `CONFIG_BOARD_REVISION` Kconfig string that represents
    our semantic versioning for board revisions, the ZigBee sample requires
    an integer representation of it. Instead of conditioning the integer
    version on the string version only for that sample and having to touch
    the ZigBee sample whenever we add a revision, I decided to have a
    board-wide config, so that both string and int versions live close to
    each other.
    Fixes #138.
2023-06-27 [ZigBee sample] Implements factory reset via SW1 button (hardware v2.0.0+)
2023-07-01 [zb] Debugging changes:
    - Disables double reset
    - Fully reset with zb_reset() on reset watchdog instead of
    user_input_indicate()
    - Debug counters before/after sensors read
    [main.c]
2023-07-01 Fixes (minor?) issues with the ZigBee sample
    1. zigbee_configure_sleepy_behavior must be called before zigbee_enable - [source
    docs](https://developer.nordicsemi.com/nRF_Connect_SDK/doc/latest/nrf/libraries/zigbee/zigbee_app_utils.html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)
    2. zb_zdo_pim_set_long_poll_interval must be called after the network is joined - [source docs](https://developer.nordicsemi.com/nRF_Connect_SDK/doc/zboss/3.5.2.0/group__zdo__poll__control.html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).
    On top of that, the argument for the call was incorrect - it expects ms directly.
    3. Removed the unecessary CONFIG_PM, seems like there's no impact in power consumption. Could it cause some weird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
    [main.c]
2023-07-01 More fixes to the ZigBee sample
    - 🚨 Missing `break` statements in `zboss_signal_handler`
    - Makes `zboss_signal_handler` return fast. According to the
    [docs](https://infocenter.nordicsemi.com/index.jsp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):
    "Signal processing should not do long operations synchronously". I
    removed calls to `prst_flash_led` (essentially a huge sync delay) and `debug_counters_increment`,
    which were blocking. I'll try migrating the debug_counters to
    non-blocking separately
    - Main sensor reading task is started for the first time upon
    the `ZB_ZDO_SIGNAL_SKIP_STARTUP` signal. This is what the
    [weather_station sample](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
    [main.c]
2023-07-01 Add missing prst_led_off after stopping LED flashing timer
    [main.c]
2023-07-01 Nuclear reset option if recurring sensor task cannot be rescheduled
    Famous last words: "this should never happen"
    [main.c]
2023-07-02 Slightly Modified High Airflow Case
    Removed the circular supports the extended all the way to the build plate and left small bumps at the top of the case. Replaced with slightly wider and flatter supports that fit within the case constraints. Also slightly enlarged the PCB groove. I found it way too tight and ended up ripping off a batter holder and pads during removal.
    [b_parasite_case_high_airflow_v2.stl]
2023-07-02 Replace Current High Airflow Cases
    [b_parasite_case_high_airflow.3mf, b_parasite_case_high_airflow.stl]
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2023-07-15 Better error handling for SHTC3 reading
    [main.c, shtc3.c]
2023-07-23 [ble] __ASSERT initialization & sensor reading
    After we tracked down a rare, annoying bug for the zigbee sample in #150,
    this PR does something similar for the ble sample. If there's an error
    either initializing the board of reading the sensors, __ASSERT will
    reboot the system, instead of letting it hang forever.
    [main.c]
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2023-08-29 Created a holder for 10 b-parasides
    Created a simple 3d printable holder for dealing with a bigger number of b-parasides.
    [B-paraside-halter_v2.3mf]
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2023-11-07 Uses newwer FIXED_PARTITION_ID for fs_mount_t
    ... This is what new samples use, but there should be no functional
    difference.
2023-11-07 Fix nRF52833 flash partitions
    The nRF52833 has only 512 kB of flash. The .dts file was incorrect, as a
    product of having it forked from the nRF52840 .dts files, which has 1 MB
    of flash.
    The new, correct partitions are closely related to the
    [nrf52833dk](https://github.com/zephyrproject-rtos/zephyr/blob/ec527228613e2768caaddedaa5cdea04951d3a06/boards/arm/nrf52833dk_nrf52833/nrf52833dk_nrf52833.dts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).
2024-01-07 Small typo fix in BLE sample README
2024-02-14 Only read positive voltages in adc.c
    The ADC sometimes responds with negative voltages read on the ADC input due to noise. This can lead to very high illuminance readings at night (4095 << 4 to be exact due to two's complement :) ).
    This commit caps ADC readings at 0.
    [adc.c]
2024-02-25 Updated BOM to changed inventory of JLCPCB. Changed D1 to equivalent component.
    [parasite.csv]
2024-02-25 Reflected changes to D1 in kicad files.
    [parasite.kicad_pcb, parasite.kicad_sch]
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2024-04-20 Update encoding.c to fix formatting errors
    [encoding.c]
2024-04-29 Fixed Typos, deleted model
    [B-paraside-halter_v2.3mf]
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2024-10-15 SDK 2.7.0 -- implicit double promotion warnings fix
    In [018dbcfd6679c273842084ce34c167295bc6f354](https://github.com/zephyrproject-rtos/zephyr/commit/018dbcfd6679c273842084ce34c167295bc6f354),
    Zephyr introduced the -Wdouble-promotion compiler flag.
    We have some debugging logs that implicitly promote floats to double,
    and it generates a lot of warnings. This commit fixes it.
    [adc.c, sensors.c, shtc3.c]
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2024-10-15 Fix double promotion warning in soil-read-loop sample
    [main.c]
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2026-08-16 fix: SHTC3 sensor link in README
